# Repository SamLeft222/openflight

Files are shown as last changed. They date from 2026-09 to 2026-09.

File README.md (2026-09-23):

<p align="center">

  DIY Golf Launch Monitor using the OPS243-A Doppler Radar.
</p>

<p align="center">
  <a href="https://discord.gg/w8hhG4WVMN">
    
  </a>
  <a href="https://buymeacoffee.com/colemangolfs">
    
  </a>
</p>

<p align="center">
  Related projects:
  <a href="https://github.com/open-flight/openflight-enclosure">Enclosure</a>
  &middot;
  <a href="https://github.com/open-flight/openflight-mobile">Mobile App</a>
</p>

> [!WARNING]
> **This project is in active development.** Features may be incomplete, unstable, or change without notice. Contributions and bug reports are welcome!

## Overview

OpenFlight is an open-source golf launch monitor built around the OPS243-A
Doppler radar, with an optional TI IWR6843 angle radar.

### What It Measures

- **Ball Speed**: 15-200 mph range with ±0.5% accuracy (OPS243-A)
- **Club Speed**: Detected from pre-impact readings (OPS243-A)
- **Smash Factor**: Ball speed / club speed ratio
- **Launch Angle**: Measured by the IWR6843; estimated when no trusted radar angle is available
- **Club Path**: Experimental pre-impact estimate from the IWR6843
- **Spin Rate**: Experimental candidate from rolling-buffer I/Q; not used for carry by default
- **Carry Distance**: Ballistic model with explicit fallbacks for missing measurements

### Hardware at a Glance

| Component | What it does | ~Cost |
|---|---|---|
| OPS243-A Radar | Ball speed, club speed, experimental spin | $249 |
| Raspberry Pi 5 | Runs everything | $130 |
| 7" Touchscreen | Shows shot data | $46 |
| SparkFun SEN-14262 | Impact sound trigger for shot capture | $18 |
| Power supply + accessories | | $27 |
| **Subtotal, no angle radar** | | **~$400** |
| TI IWR6843LEVM + cable | Launch angle, experimental club path | $156 |
| **Total with angle radar** | | **~$556** |
| K-LD7 (×2) + FTDI adapters | Launch angle + club path (**deprecated**) | $140 |

Without an angle radar you still get ball speed, club speed, smash factor,
experimental spin, and estimated carry. The angle radar adds measured launch
angle and experimental club path.

> **⚠️ The K-LD7 angle radars are deprecated.** The supported angle radar is now the **TI IWR6843**. Don't buy K-LD7s for a new build; their software support remains for existing builds only. See the [full parts list](docs/get-started/parts.md) for details and links.

> **The IWR6843 needs custom firmware** — the stock TI demo doesn't expose the raw radar cube OpenFlight needs. A validated prebuilt image ships in `firmware/releases/`, so flashing it doesn't require the TI toolchain. See the [IWR6843 Operator Guide](docs/iwr6843/index.md).

## Getting Started

### 1. Get the parts

See the **[Parts List](docs/get-started/parts.md)** for everything you need with purchase links.

### 2. Wire it up

Follow the **[Sound Trigger Wiring Guide](docs/build/sound-trigger.md)** to connect the SEN-14262 to the OPS243-A. The (deprecated) K-LD7 modules connect via USB — no wiring needed.

**Adding the IWR6843 angle radar?** The Pi cannot power both radars over USB, so
the OPS243 moves to the Pi's GPIO UART header while the TI board takes the USB
port. Do it in this order, validating each step before the next — doing both at
once makes any failure ambiguous:

1. **[Move the OPS243 from USB to the Pi GPIO UART](docs/build/ops243-uart.md)** — rewire and confirm the OPS still triggers on its own.
2. **[IWR6843 Operator Guide](docs/iwr6843/index.md)** — wire, flash the firmware, mount, aim, and measure geometry.

If your OPS243-A has **WiFi**, you cannot use the GPIO UART — its WiFi module
already drives the radar's UART receive line. Use a separately powered USB hub
instead; see the operator guide's Option B.

### 3. Set up the Pi

Flash Raspberry Pi OS (64-bit), plug in the radars, then run the interactive setup:

```bash
git clone https://github.com/jewbetcha/openflight.git
cd openflight
./scripts/setup/setup.sh
```

The script installs everything and walks you through the one-time hardware
configuration (radar flash setup, legacy K-LD7 device naming, auto-start, and
optional cloud sync) with prompts. It's safe to re-run any time.
See the **[Raspberry Pi Setup Guide](docs/setup/raspberry-pi.md)** for details and troubleshooting. Touchscreen installations can use the **[Startup Splash Screen](docs/setup/splash-screen.md)** guide to install a terminal-free desktop launcher with immediate startup progress.

### 4. Hit balls

```bash
# Default: rolling buffer mode with sound trigger
scripts/start-kiosk.sh

# With the IWR6843 angle radar (OPS243 on the Pi GPIO UART).
# Geometry values are examples — measure your own; see the operator guide.
scripts/start-kiosk.sh --iwr6843 \
  --ops-port /dev/ttyAMA0 \
  --iwr6843-tee-m 1.372 --iwr6843-net-m 4.064 \
  --iwr6843-tilt-deg 5.5 --iwr6843-radar-height-m 0.229 \
  --iwr6843-ball-height-m 0.021

# With legacy K-LD7 hardware (measure the mount tilt first)
scripts/start-kiosk.sh --kld7 --kld7-mount-tilt <measured-degrees>

# Swing speed training (air swings / speed sticks, no sound trigger)
scripts/start-kiosk.sh --swing-speed

# Development mode (no hardware)
scripts/start-kiosk.sh --mock

# With Geekworm X1202/X1206 battery monitoring
scripts/start-kiosk.sh --battery geekworm
```

The IWR6843 example values are not universal. Measure the geometry from the
antenna center and follow the [operator guide](docs/iwr6843/mounting.md#measure-the-geometry);
wrong values bias the result instead of producing an obvious startup error.

Then open http://localhost:8080 or use the touchscreen. Footer tabs switch
between Live, Stats, Shots, Camera, Players, and Debug. Tap the footer logo for
units, theme, and language; the footer power icon opens shutdown confirmation.
On Live, tap a metric to pin it top-left while keeping all metrics visible. Use
the Replay action on camera-backed shots to open a touch-friendly slow-motion
impact clip. The MP4 is generated only when Replay is selected and is cached
beside the raw camera capture. For a TV or tablet, use
[TV Display Mode](#tv-display-mode).

### 5. Sync to the cloud (optional)

OpenFlight can push your sessions to the **FlightWeb** cloud so you can review
shots from any device. It's opt-in, and **raw radar data never leaves your
Pi** — only shot results and session metadata are uploaded (verify with
`openflight-cloud push --dry-run`).

`setup.sh` offers to enable this and link your Pi. To do it by hand:

```bash
openflight-cloud link       # pair this Pi (enter a short code in your browser)
openflight-cloud status     # linked? queued? parked?
```

Once linked, sessions sync automatically (on session end and via a ~10-minute
timer that heals wifi outages). See the **[Cloud Sync Guide](docs/using/cloud-sync.md)**
for details.

### TV Display Mode

OpenFlight also serves a fullscreen-friendly browser display for tablets, TV browsers, or a Chrome tab cast to Chromecast.

1. Start OpenFlight as usual with `scripts/start-kiosk.sh`.
2. Find the OpenFlight host on your LAN — its hostname (see below) or its IP address.
3. Open `http://<openflight-host>:8080/display` from another laptop, tablet, or TV browser.
4. For Chromecast, open the display page in Chrome and use Chrome's built-in **Cast** feature to cast the tab.

> **Prefer the hostname over the IP.** Raspberry Pi OS broadcasts its hostname over
> mDNS (Avahi), so `http://openflight.local:8080/display` keeps working even when the
> Pi's DHCP lease expires and it comes back on a different address — a bookmarked IP
> breaks unless you reserved it on your router. Set the name in Raspberry Pi Imager's
> **Hostname** field when you flash the card; the default is `raspberrypi`, i.e.
> `raspberrypi.local`. The viewing device has to support mDNS — macOS, iOS, Windows 10+
> and most Linux desktops do, but some smart-TV browsers don't, so use the IP there.

This is browser/tab casting only. OpenFlight does not include native Cast SDK support yet.

### Swing Speed Training

For air swings and speed-stick training, OpenFlight can use the OPS243-A fast
speed stream directly instead of waiting for impact audio. Start it with
`scripts/start-kiosk.sh --swing-speed`; the server emits `swing_speed` events
with peak club speed, rep duration, reading count, and session stats. See the
**[Swing Speed Training Guide](docs/using/swing-speed.md)** for setup and
tuning options.

## How It Works

### System Architecture

```
SEN-14262 ── trigger ──► OPS243-A ── I/Q ──► RollingBufferMonitor
                                                   │
IWR6843 (optional) ── angle + club path ───────────┤
                                                   ▼
                                           Flask + WebSocket ──► React UI
```

1. **Sound trigger fires** — SEN-14262 detects club impact, triggers OPS243-A HOST_INT
2. **OPS243-A dumps buffer** — I/Q data is analyzed for ball speed, club speed, and an experimental spin candidate
3. **IWR6843 correlates** — The optional angle radar uses the same impact edge for launch angle and experimental club path
4. **Carry computed** — The ballistic model uses trusted measurements and fills missing inputs with documented fallbacks
5. **UI updates** — Shot data emitted via WebSocket to the React frontend

### Doppler Radar Basics

The OPS243-A transmits a 24 GHz signal. When it bounces off a moving object (the golf ball), the frequency shifts proportionally to the object's speed — this is the Doppler effect. At 24.125 GHz, each 1 mph of speed creates a ~71.7 Hz Doppler shift.

### Positioning

Place the OPS243-A **3-5 feet behind the tee**, pointing down the target line:

```
                Ball Flight Direction
                ======================>

[Tee]  ←--- 3-5 ft ---→  [OPS243-A]
```

The IWR6843 has stricter mounting and measurement requirements; use the
[operator guide](docs/iwr6843/mounting.md#mount-and-aim-the-radar) rather than assuming it
shares the OPS243 position.

## Configuration

### Radar Settings for Golf

| Setting | Value | Why |
| --- | --- | --- |
| Mode | Rolling buffer | Raw I/Q capture for precise speeds and experimental spin |
| Sample Rate | 30 ksps | Supports up to ~208 mph ball speed |
| Capture | 4096 I/Q samples | ~136 ms around impact |
| Trigger | Sound (SEN-14262) | ~10 µs hardware latency via HOST_INT |
| Min Ball Speed | 15 mph | Minimum valid ball speed threshold (35 mph for speed-triggered mode) |
| DC Mask | ~15 mph exclusion zone | Reject body movement and environmental noise |

These are applied automatically — the one-time flash configuration is handled
by the setup script.

### Python API

```python
from openflight.rolling_buffer import RollingBufferMonitor

monitor = RollingBufferMonitor()   # auto-detects the OPS243-A
monitor.connect()
monitor.start()

print("Swing when ready...")
shot = monitor.wait_for_shot(timeout=60)
if shot:
    print(f"Ball Speed: {shot.ball_speed_mph:.1f} mph")
    print(f"Est. Carry: {shot.estimated_carry_yards:.0f} yards")

monitor.stop()
monitor.disconnect()
```

## Limitations

- **Cosine error**: If ball doesn't travel directly toward/away from radar, measured speed will be slightly lower than actual
- **Spin detection**: The live multitaper value is experimental and is not used for carry by default. Short indoor flight windows and multipath make individual readings unreliable; see [Rolling Buffer and Spin Detection](docs/how-it-works/rolling-buffer.md).
- **K-LD7 speed aliasing** (deprecated hardware): The K-LD7 max speed is 62 mph, so it's used only for angle/distance, not speed

## Hardware Diagnostic

To verify the OPS243, sound trigger, and legacy K-LD7 path:

```bash
uv run python scripts/hardware-test/diagnose.py
```

The diagnostic checks the OPS243 transport, rolling-buffer persistence,
software and hardware triggers, and any connected K-LD7 radars. IWR6843 builds
use the [operator guide's first-capture checks](docs/iwr6843/verify.md#verify-the-first-capture).

Missing optional hardware (like the horizontal K-LD7) is reported as a skip rather than a failure. Pass `--require-all` to fail on skips, or `--no-interactive` to skip the sound-trigger prompt in unattended runs.

## Project Structure

```
openflight/
├── src/openflight/
│   ├── ops243.py              # OPS243-A radar driver
│   ├── launch_monitor.py      # Shot detection & club/ball separation
│   ├── server.py              # Flask server and shot orchestration
│   ├── session_logger.py      # JSONL session logging
│   ├── rolling_buffer/        # OPS capture and signal processing
│   ├── iwr6843/               # Current angle radar
│   ├── kld7/                  # Legacy angle radar
│   ├── sim/                   # Simulator connector framework
│   └── cloud/                 # FlightWeb uploader
├── ui/                        # React frontend
├── scripts/                   # Utility & setup scripts
├── docs/                      # Documentation
└── pyproject.toml
```

## Community

Join the **[OpenFlight Discord](https://discord.gg/w8hhG4WVMN)** to ask build
questions, share results, and follow development.

## Contributing

Contributions welcome! See [CONTRIBUTING.md](CONTRIBUTING.md) for guidelines.

Areas of interest:

- **Better spin detection**: A dechirped Doppler-sideband estimator is in development (`scripts/analysis/replay_spin_dechirp.py`) — help validating it against launch-monitor truth data is especially welcome
- **Mobile app**: Bluetooth connection to phone

### Running Tests

```bash
uv run pytest tests/ -v
```

## Documentation

📖 **Full documentation site: <https://openflight.dev/docs/>**

Build it locally with `make docs` (serves at `localhost:8000`).

- **[Parts List](docs/get-started/parts.md)** — What to buy
- **[Sound Trigger Wiring](docs/build/sound-trigger.md)** — How to wire the sound trigger
- **[Raspberry Pi Setup](docs/setup/raspberry-pi.md)** — Full setup guide
- **[Electron Kiosk Shell](docs/electron-kiosk-shell.md)** — Why the kiosk runs in Electron and how self-updating could work later
- **[Battery Monitoring](docs/using/battery.md)** — Provider architecture, UI states, and shared Pi support
- **[Geekworm X1202/X1206 Operator Guide](docs/build/battery.md)** — Batteries, Pi setup, native telemetry, and warnings
- **[IWR6843 Operator Guide](docs/iwr6843/index.md)** — Wire, flash, mount, aim, and calibrate the angle radar
- **[LIS3DH Inclinometer Setup](docs/build/inclinometer.md)**: Add enclosure-level compensation to IWR6843 tilt
- **[OPS243 USB → GPIO UART Migration](docs/build/ops243-uart.md)** — Required before adding the IWR6843
- **[IWR6843 Firmware Developer Guide](docs/development/firmware.md)** — Build the firmware from source (not needed to flash the prebuilt image)
- **[Enclosure & Case](docs/build/enclosure.md)** — The printed IARC v3 case
- **[Hardware Diagnostic](docs/setup/raspberry-pi.md)** — Pi setup, auto-start, and troubleshooting
- **[Simulator Connectors](docs/using/simulator/index.md)** — Stream shots to GSPro, OpenGolfSim, PAR-TEE, and others
- **[Cloud Sync](docs/using/cloud-sync.md)** — Push filtered sessions to FlightWeb
- **[Rolling Buffer & Spin Detection](docs/how-it-works/rolling-buffer.md)** — Production capture and experimental spin details
- **[Dechirped-Sideband Spin Replay](docs/development/spin-replay.md)** — Next-gen spin estimator test bench
- **[Camera and YOLO Experiments](docs/development/camera-yolo.md)** — Optional, non-production vision work
- **[Legacy K-LD7 Setup](docs/legacy/index.md)** — Existing K-LD7 builds only
- **[K-LD7 Ball Detection Theory](docs/legacy/ball-detection-theory.md)** — How angle detection works (deprecated hardware)
- **[Observability & Log Shipping](docs/using/observability.md)** — Ship logs to Grafana Cloud
- **[Contributing Guide](CONTRIBUTING.md)** — How to contribute
- **[Changelog](docs/changelog.md)** — Version history

## License

GNU Affero General Public License v3.0 or later (AGPL-3.0-or-later) - see LICENSE file.

## Acknowledgments

- [OmniPreSense](https://omnipresense.com/) for the OPS243-A radar and documentation
- The golf hacker community for inspiration

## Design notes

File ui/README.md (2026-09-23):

# OpenFlight UI

The OpenFlight dashboard: a React + TypeScript + Vite app that connects to the
backend over `socket.io`. The kiosk is a tabbed instrument panel (Live, Stats,
Shots, Camera, Profiles, Debug) plus a screen-mounted display mode at `/display`.

This README covers frontend development. For the hardware, the radar pipeline,
and how the whole system fits together, see the [root README](../README.md).

## Quick start

You need Node 22.12 or newer (`electron@44` will not install cleanly on Node 20).

### Frontend-only (recommended for UI work)

Runs Vite plus a Node Socket.IO mock on port `8080` — no Python, hardware, or
`uv` required:

```bash
npm install
npm run dev:mock
```

Open `http://localhost:5173`. Use **Simulate** to generate shots. The mock
speaks the same Socket.IO events as the real backend (`shot`, `session_state`,
club/profile changes, clear/delete, stub cloud upload and shutdown).

### Against the real / Python mock backend

Start a backend without hardware from the repo root:

```bash
scripts/start-kiosk.sh --mock
```

Then in `ui/`:

```bash
npm install
npm run dev
```

See the [root README](../README.md#getting-started) for full-stack options.

The Vite server runs on port `5173`. When served there, the UI assumes the
backend is at `http://localhost:8080`. Point it elsewhere with
`VITE_SOCKET_URL`:

```bash
VITE_SOCKET_URL="http://localhost:8081" npm run dev
```

`/api/*` requests from the Vite origin are proxied to `http://localhost:8080`
(so shutdown works under `npm run dev` / `dev:mock`).

## Scripts

| Script | Description |
| --- | --- |
| `npm run dev` | Dev server with hot reload (needs a backend) |
| `npm run dev:mock` | Vite + Node mock backend on port 8080 |
| `npm run mock-server`  | Node mock Socket.IO server alone |
| `npm run build` | Type-check and build the production bundle |
| `npm run preview` | Serve the production build locally |
| `npm run lint` | ESLint |
| `npm run test` | Vitest unit tests |
| `npm run format` | Format `src/` with Prettier |
| `npm run format:check` | Check formatting without writing |

## How the UI connects

The app is entirely client-side. Everything flows through one socket connection.

- **`utils/serverOrigin.ts`** resolves the backend origin: `VITE_SOCKET_URL` if
  set, otherwise `http://localhost:8080` when running on the Vite dev port
  (`5173`), otherwise the page's own origin (the production case, where the
  backend serves the built UI).
- **`services/socketService.ts`** owns the connection. It receives events like
  `shot`, `session_state`, `camera_capture_settings`, and `trigger_status`, and
  sends commands like `set_club`, `clear_session`, `simulate_shot`, and
  `set_camera_capture_settings`. Read it before assuming what the
  backend emits. **`mock-server/`** implements that contract in Node for
  `npm run dev:mock`.
- **State** lives in `stores/` (Zustand: shots, system, camera, debug, profiles, …).
- **Shutdown** posts to `/api/shutdown` to stop the connected backend (stubbed
  as a no-op by the Node mock).

### Profiles socket contract

Shots are attributed to a server-owned **profile** — a person or a place — with
a stable id. There is no browser-local roster: the server is the only source of
truth, sent as one snapshot plus five mutations.

Server → client:

- `profiles` — `{ profiles: Profile[], active_profile_id: string }`. Sent on
  connect and after every mutation below. `Profile` is
  `{ id, name, created_at, settings }`.
- `session_cleared` — `{ profile_id: string, shots: Shot[] }`, sent after
  `clear_session`.

Client → server:

- `get_profiles` — request a fresh `profiles` snapshot.
- `set_active_profile` — `{ profile_id }`. Switches which profile new shots
  attribute to.
- `add_profile` — `{ name }`. Creates a profile and makes it active.
- `rename_profile` — `{ profile_id, name }`. Renames in place; the id (and
  every shot already attributed to it) is unchanged.
- `remove_profile` — `{ profile_id }`. The server refuses to remove the active
  profile, the last remaining profile, or a profile that still has session
  shots. Clear that profile's session first.
- `clear_session` — `{ profile_id }` (defaults to the active profile).
  Deletes that profile's shots; other profiles are untouched.

Shots carry `profile_id` and `profile_name` (a snapshot at capture time) for
logging / external consumers. The kiosk UI renders the current profile name
from the `profiles` roster (joined by `profile_id`), so renaming updates the
on-screen name for past shots.

**Kiosk shell.** Footer tabs switch views. The footer logo opens a sheet for
units (MPH/YDS vs KMH/M), dark/light theme, language, and simulator status.
The footer power icon is always visible and opens a
shutdown confirmation. Change club (or training implement) lives on the Live
header. Tap a Live metric to pin it top-left while keeping all metrics visible.
Camera-backed shots add a **Replay** action in the Live header and a play button
in Shots. Selecting either action asks the backend to lazily create and cache a
60 FPS MP4; no video conversion runs automatically after a shot. The full-screen
player includes touch controls, a scrubber, an impact marker, and retryable
preparation/playback errors.

The pin is stored in
`localStorage` under `openflight.hero-metric`. Theme is stored under
`openflight.theme` (default dark). Those keys live in the **current browser
profile**. Electron does not share Chromium's profile; see
[Electron Kiosk Shell](../docs/electron-kiosk-shell.md#browser-local-state-breaking-on-first-electron-launch).

**Display mode** lives at `/display`: a compact, fullscreen-friendly dashboard
for mounted screens and TVs. The [root README](../README.md#tv-display-mode)
covers casting it.

**Launch Daddy** is a hidden overlay. Five taps on the header connection LED
and title toggle it. When on, new shots can fire an animation; tap the brand
mark to turn it off.

Touch and type conventions for the Pi kiosk are in [`AGENTS.md`](./AGENTS.md).

## Languages

UI copy lives in `src/i18n/`. English, Spanish, French, and Portuguese ship
today. Pick a language from the footer menu (**Language** dropdown). The choice
is stored in `localStorage` under `openflight.locale:v1`.

### Add a language

1. Copy `src/i18n/en.ts` to `src/i18n/<code>.ts` (use a short BCP 47 language
   code such as `de` or `ja`).
2. Translate every value. Keep the same keys; TypeScript will fail the build if
   a key is missing.
3. Register it in `src/i18n/index.ts`:
   - Add the id to `LocaleId`.
   - Add `{ id, nativeName, htmlLang }` to `LOCALES` (`nativeName` is the
     language’s own name, shown in the dropdown).
   - Import the catalog and add it to `catalogs`.
4. Run `npm test` — a catalog that drifts from English keys fails.

Do not translate profile names, club tile codes (`7i`, `DR`), or unit
abbreviations (`MPH` / `YDS`).

## Project layout

A few files do most of the work. This is illustrative, not exhaustive —
components carry co-located `.css` and `.test.tsx` files.

```text
src/
  App.tsx                    # tabs, display routing, session wiring
  main.tsx                   # entry point (applies stored theme)
  i18n/                      # EN/ES/FR/PT catalogs
  theme/                     # dark/light tokens
  services/socketService.ts  # socket connection, events, backend commands
  hooks/useSocket.ts         # connects on mount
  utils/serverOrigin.ts      # backend origin resolution
  stores/                    # Zustand (shots, system, camera, profiles, …)
  components/
    panel/                   # Live, Stats, Shots, Camera, Profiles, chrome
    ui/                      # MetricCard, TabBar, Button, SegmentedControl
    DisplayMode.tsx          # /display
    DebugPanel.tsx
    LaunchDaddy/             # hidden overlay
mock-server/                 # Node Socket.IO mock for frontend-only development
```

## Troubleshooting

**Socket won't connect.** Confirm a backend is running on port `8080` (or set
`VITE_SOCKET_URL`). For UI-only work, use `npm run dev:mock`. Connection logs
come from `services/socketService.ts`.

**Build fails.** `npm run build` surfaces TypeScript and bundling errors; `npm
run lint` catches the rest.

---

Contributing guidelines (setup, code quality, PRs) live in
[CONTRIBUTING.md](../CONTRIBUTING.md).

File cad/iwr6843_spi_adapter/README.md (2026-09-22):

# IWR6843LEVM → Raspberry Pi 5 SPI adapter

Small 2-layer board (34.0 × 25.9 mm) that plugs into the IWR6843LEVM's 60-pin
**J1** (MMWAVEICBOOST) connector and brings the radar's SPI-A port out to a
0.1" header for jumper wires to the Pi 5. The goal is to move the ~733 KB
wide-profile dump over SPI (~0.6 s at 10 MHz) instead of the ~1 Mbaud CP2105
UART (~7 s).

> **Status: rev A, not yet built or tested.** ERC, DRC and schematic–PCB
> parity pass. The firmware SPI path and Pi driver do not exist yet.

## What's on the board

| Ref | Part | Job |
|---|---|---|
| J1 | Samtec **QTH-030-01-L-D-A** (bottom side) | Mates the LEVM's J1 (QSH-030-01-L-D-A), 5.00 mm stack |
| J2 | 1×11 2.54 mm header (top side) | Jumpers to the Pi 5 |
| U1, U2 | SN74LVC2G34DBVR, powered by **radar 3V3** | Pi → radar: SCLK, MOSI, CS (U2 ch1 spare, input grounded) |
| U3 | SN74LVC2G34DBVR, powered by **Pi 3V3** | Radar → Pi: MISO, HOST_INTR |
| R1 | 100k to radar 3V3 | CS inactive (high) while the Pi pin is floating |
| R2–R5 | 100k to GND | No floating buffer inputs (SCLK, MOSI, MISO, INTR) |
| R6, R7 | 33 Ω | Damp ringing on the INTR/MISO jumpers |
| C1–C3 | 100 nF | Buffer decoupling (C3 is on the bottom) |

**Why buffers:** the IWR6843's digital I/O is not failsafe (TI SWRU585: do not
drive the pins without VIO present). The LVC2G34 has Ioff partial-power-down
(≤10 µA leakage at VCC = 0), so whichever side loses power, its buffer goes
inert and nothing back-feeds the unpowered chip.

## Before ordering (can't be checked in software)

1. **Mating orientation.** The footprint assumes QTH pin *n* mates LEVM J1
   (QSH) pin *n*, with the −A alignment pins on the row-01 side (per the
   Samtec land pattern). Print `fab/gerbers/*B_Cu*` at 1:1, or check a
   Samtec mated-pair drawing, and confirm pin 1 against the LEVM's J1
   silkscreen.
2. **Clearance behind the LEVM.** The adapter sits 5 mm under the LEVM's
   bottom side. The only bottom-side parts are J1, C3 (0.9 mm) and **J2's
   pin tails, which must be trimmed flush (≤1 mm)** so they can't touch the
   LEVM's bottom components (J6 is nearby).

## Ordering and assembly (PCBWay turnkey)

Run `./export_fab.sh` (regenerates, runs ERC/DRC, and exports into `fab/`):

| Upload | File |
|---|---|
| Gerbers + drills | `fab/iwr6843_spi_adapter-gerbers.zip` |
| BOM (PCBWay columns, MPNs) | `fab/pcbway_bom.csv` |
| Centroid / CPL | `fab/pcbway_cpl.csv` (origin = board lower-left, J2 excluded) |
| Assembly drawings | `fab/assembly/assembly_top.pdf`, `fab/assembly/assembly_bottom_mirrored.pdf` |

PCB options: 2 layers, FR-4, 1.6 mm, 1 oz, **ENIG** (flat pads for the
0.5 mm-pitch J1; HASL is too uneven), min track/spacing 5/5 mil, min hole
0.3 mm, tented vias, any mask colour.

Assembly: turnkey, **both sides** (J1 and C3 on the bottom, the rest on top).
J2 is not in the BOM or CPL. Solder it yourself and trim the tails flush.
Notes to include with the order:

> J1 (Samtec QTH-030-01-L-D-A) is on the BOTTOM side; its -A alignment pins go
> into the two 1.02 mm NPTH holes; pin 1 is marked on the bottom assembly
> drawing. U1-U3 pin 1 per the silkscreen dot. J2 (1x11 header) is NOT
> assembled. Please send placement confirmation images before production.

## LEVM setup

* Set switch **S1.4 OFF**. This routes SPI-A through the on-board TS3A5018
  mux to J1 instead of the CAN transceivers (PROC116A sheet 13). OpenFlight
  does not use CAN. TI's "functional mode" table leaves S1.4 ON; that is
  the only change.
* Keep powering the LEVM over USB as today. Do not connect J1 pin 2 (5V).

## Pi 5 wiring (jumpers ≤15 cm, cable-tie each signal to its GND)

| Adapter J2 | Signal | Pi 5 pin |
|---|---|---|
| 1 | 3V3 (powers U3) | 1 |
| 2, 4, 6, 8, 10 | GND | 6, 9, 14, 20, 25 |
| 3 | HOST_INTR (data ready) | 22 (GPIO25) |
| 5 | MISO | 21 (GPIO9) |
| 7 | MOSI | 19 (GPIO10) |
| 9 | SCLK | 23 (GPIO11) |
| 11 | CS | 24 (GPIO8 / CE0) |

None of these clash with the OPS243 UART wiring (Pi pins 2/4, 6, 8, 10, 11).
Enable SPI with `dtparam=spi=on`. Start at ≤10 MHz on jumpers.

## First power-up checks

1. Adapter only, unplugged from the LEVM: continuity between J2 even pins and
   J1 GND. No short between Pi 3V3, radar 3V3 and GND.
2. Plugged in, **everything off**: beep from J1-side nets to the LEVM's 0 Ω
   links: CS → R7, SCLK → R9, MOSI → R11, MISO → R12, INTR → R10
   (PROC116A sheet 8). This confirms the mating orientation.
3. Power the LEVM only: radar 3V3 is present at C1/C2 and U3 stays unpowered.
   Then the Pi only, then both.

## Sources

| Fact | Source |
|---|---|
| J1 pins 19/21/23/25 = SPI CS/CLK/MOSI/MISO, 16 = HOST_INTR, 4/6 = 3V3, even 20–50 = GND | TI PROC116A schematic, sheets 5, 8, 13 |
| VIOIN = 3.3 V, SPI-A behind TS3A5018, S1.4 selects SPI/CAN | PROC116A sheets 5 and 13; SWRU585 table 5-1 |
| J1 = QSH-030-01-L-D-A | PROC116A BOM |
| QTH land pattern, 5.00 mm mated height | Samtec QTH footprint Rev D, QTH print table 1 |
| LVC2G34 pinout, Ioff, DBV0006A land pattern | TI SN74LVC2G34 datasheet |

## Regenerating

Everything is generated from `generate.py` (schematic, footprints, project)
and `build_pcb.py` (placement, routing, pours). `NETS`/`PARTS` are the single
source of truth for both. Edit those, never the KiCad files.

```bash
K=/Applications/KiCad/KiCad.app/Contents
$K/Frameworks/Python.framework/Versions/Current/bin/python3 generate.py
$K/MacOS/kicad-cli sch erc --severity-all iwr6843_spi_adapter.kicad_sch
$K/MacOS/kicad-cli pcb drc --schematic-parity --refill-zones --severity-all iwr6843_spi_adapter.kicad_pcb
```

Expect only `lib_symbol_issues` / `lib_footprint_issues` warnings if your
KiCad has no global library tables configured. They are environment notices,
not design errors.

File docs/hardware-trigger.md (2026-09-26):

# OPS243 Internal Hardware Trigger

OpenFlight’s `hardware` trigger mode lets the OPS243-A decide when a rolling-buffer capture starts. It is opt-in; the kiosk default remains the existing SEN-14262 sound trigger.

## OPS243 firmware prerequisite

Hardware-trigger mode requires **OPS243-A firmware v1.3.2 or newer in the 1.3
release train**. Firmware v1.3.1 has a vendor data-sequence bug and is rejected.
The driver queries `?V` before sending the internal trigger setup commands and
fails fast if the reported version is from an older or different release train,
malformed, or unavailable. Update the physical OPS243 using the manufacturer’s
firmware procedure before running `--trigger hardware`; this application does
not flash the radar.

## Methodology

The host configures the radar once and then waits for the radar’s completed rolling-buffer dump. The host does not poll speed reports or send `S!` for each shot:

1. Put the radar in idle mode with `PI`.
2. Set a temporary outbound `ST-90` guard before entering rolling-buffer mode.
   `GC` can restore the detector units to m/s before `US` is sent; 90 is below
   the 30 ksps ceiling of 93.2 m/s and is still above ordinary startup motion
   if the board retained mph units.
3. Enter rolling-buffer mode with `GC`, then resend the guard because `GC`
   resets detector settings.
4. Restore the detector settings that `GC` resets: 30 ksps and MPH units first,
   then raise the temporary guard to `ST-200` while the remaining settings are
   written: 128 samples, `X=2`, outbound filtering, JSON plus magnitude output,
   and the configured `S#n` split.
5. Restore the magnitude gate `SMn`, then restore the requested `ST-n` last and allow the 4,096-sample history to fill.
6. Wait for the board-triggered dump, parse the I/Q payload, and reject it if it has no outbound ball-speed reading at or above 35 mph.
7. Re-arm with the same temporary guard around `GC`, restore the cached settings, and wait for the buffer to fill again. A serial write timeout keeps the capture and reports a retryable re-arm failure instead of discarding the shot.

The implementation is intentionally limited to the OPS243 trigger path; the
experimental analysis and UI work remain outside this focused change.

## Defaults and command

| Setting | Hardware-mode default |
|---|---:|
| Trigger threshold | 25 mph |
| Trigger magnitude | 25 (`SM25`) |
| Pre-trigger split | 6 segments (`S#6`) |
| Sample rate | 30 ksps (required) |
| Minimum accepted outbound ball speed | 35 mph |

Run the mode directly with:

```bash
openflight-server \
  --trigger hardware \
  --trigger-threshold 25 \
  --trigger-magnitude 25 \
  --pre-trigger-segments 6 \
  --sample-rate 30
```

The kiosk script forwards the same settings:

```bash
scripts/start-kiosk.sh --trigger hardware
```

Use `--trigger-threshold`, `--trigger-magnitude`, and `--pre-trigger-segments` to override the hardware path. `S#6` applies only to this new mode. The established sound path continues to use `--sound-pre-trigger` and keeps its existing default and behavior:

```bash
scripts/start-kiosk.sh --trigger sound --sound-pre-trigger 16
```

The internal trigger does not depend on the SEN-14262 sound edge. Existing sound-trigger wiring can remain installed, but selecting `hardware` is the software choice that activates the OPS243 internal trigger.

## Raspberry Pi retest checklist

Before treating a PR as ready for merge, run the hardware path on the target Pi and record the observations in the PR body:

Also run the unchanged sound path with the same representative shots:

```bash
scripts/start-kiosk.sh --trigger sound
```

I was unable to regression test the sound trigger.

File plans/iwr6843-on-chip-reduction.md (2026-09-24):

# Plan: IWR6843 On-Chip Data Reduction

> Source: offline study on 2026-09-24 of 70 shots paired with a Garmin R10
> (sessions `20260923_130739`, `131647`, `134628`; dense IQ8 profile).

## Problem

The IWR6843 result arrives ~6.4 s after impact. 5.3 s of that is streaming
the full 537 KB capture over the 1 Mbaud UART; Pi processing is ~1.1 s. The
launch-angle pipeline only ever reads a small part of that capture.

## Approach

The chip sends a small **power overview** first; the Pi runs its **unchanged**
ball tracker and OPS-guided track search on it, then requests only the thin
**strips** of complex data along the chosen track (or each candidate track).
Every tracking and estimation decision stays on the Pi, so estimator changes
never require reflashing.

Measured with the Phase 0 reference model on all 77 saved captures
(`scripts/iwr6843/evaluate_reduced_transfer.py`):

| Shot type | Captures | Bytes (median) | Transfer | Today |
|---|---|---|---|---|
| Baseline track (1 strip request) | 46 | 105 KB | ~1.0 s | 537 KB, 5.3 s |
| OPS-guided search (2 strip requests) | 31 | 280 KB | ~2.7 s | 537 KB, 5.3 s |
| All | 77 | | **~1.0 s median** | 5.3 s |

Transfer times assume today's measured ~103 KB/s. The Pi must still wait for
the OPS ball speed (~1.9 s) before confirming a track, so the expected
end-to-end IWR result is ~2.5-3 s instead of ~6.4 s. These are estimates from
byte counts, not hardware measurements.

## Evidence (offline, 70 paired shots)

1. **The angle fit is local to the track.** Given the same track and the full
   capture's noise power, a +/-1-bin strip (38.5 KB IQ8) reproduced the LCMF
   angle bit-for-bit on 62/62 shots (burst MTI scope). Horizontal was
   identical on every shot that had one.
2. **The tracker and OPS-guided search read only `loop_power(mti)`** inside the
   ball gates (2.25 m to net - 0.25 m; bins 48-98 on the current profiles).
   Bins outside the gates cannot change a detection.
3. **Overview precision.** A log-encoded uint16 power map (1/256-octave steps)
   left accuracy vs the R10 unchanged (solid shots, R10 LA > 5, n = 50: typical
   2.16 deg, mean 3.81 deg, 24 within 2 deg, same as full data); median shift
   from the full-data angle 0.00 deg, one shot moved 10.7 deg. uint8 at 0.5 dB
   or 1 dB was worse (mean 4.08 / 4.53 deg, more >5 deg misses): rejected.
4. **Both MTI scopes are needed.** Running the OPS-guided search on the burst
   map only raised the mean error from 3.81 to 4.48 deg and moved one shot
   37.5 deg. The window-scope map is sent every time (27.6 KB).
5. **Tracker sensitivity.** `find_ball` is a seeded RANSAC; changing a single
   detection reshuffles its draws. Bit-identical output is therefore not a
   usable acceptance test for any change to the overview; accuracy vs a
   reference is.

## Architectural decisions

- **Decision logic stays on the Pi.** The chip computes MTI, power, and noise
  and serves strips. It never chooses a track or an angle.
- **`l3dump` is kept unchanged** as the fallback path and for `--debug` raw
  captures.
- **Overview contents** (vertical TX pair 0/2, the same data the Pi uses today):
  - burst-scope and window-scope `loop_power`, rows = frame x loop, columns =
    gate bins only, log-encoded int16 (`round(log2(p) * 256)`, with
    -32768 reserved for exactly zero);
  - burst- and window-scope noise power as float32, computed exactly as
    `PreparedShotDump.noise_power` (median of `|mti|^2` over all valid bins);
  - window-scope per-bin static means (complex64, vertical pair, every bin
    any frame window holds), so the Pi can form window-scope MTI from strips
    (~6 KB);
  - the existing per-frame descriptors (start, count, time delta) and header.
- **Strips reuse the existing v7 variable-width timed format**, IQ8 as stored,
  all 3 TX (the horizontal proxy uses the third TX). One contiguous window per
  frame; the union of candidate corridors when several tracks are requested.
  The format needs at least one bin per frame, so an unrequested frame carries
  the first bin of its window.
- **The ring stays frozen** from `l3overview` until `l3release`, or until a
  firmware timeout (proposal: 10 s) re-arms it if the Pi disappears.
- **Gate bins are configured by the Pi** (`overviewCfg <loBin> <hiBin>`,
  derived from the net distance) so firmware and tracker cannot drift.
- **Lossless vertical projection.** Today `project_tx_pair` re-quantises IQ8
  with a new per-frame scale derived from the frame's maximum. With strips
  that maximum changes, so the projection must keep the stored IQ8 values
  exactly. Offline, the lossless projection moved individual angles (median
  0.43 deg in the full pipeline) without changing accuracy vs the R10
  (typical 1.94 vs 1.79 deg, n = 43), so this is a behaviour change to accept
  deliberately, not a fix.
- **Feature flag.** The reduced transfer ships behind
  `--iwr6843-reduced-transfer` with automatic fallback to `l3dump` on any
  protocol error, timeout, or malformed response.

## Out of scope / open questions

- **Club path** (experimental) uses pre-impact frames outside the ball gates.
  Either drop it in reduced mode or request an additional club strip.
- **On-chip compute time** for MTI + power + two medians on the R4F is not
  measured; the estimate is tens of ms. The DSP stays unused.
- **UART round-trip latency** for request/response is not measured.
- **Build toolchain.** Resolved: the Docker toolchain builds the release
  byte-for-byte (Phase 1).

---

## Phase 0: Python chip model and host refactor (no firmware)

**User stories**: As a developer, I can prove on saved dumps that the reduced
transfer produces the same shots before any firmware is written.

### What to build

A reference "chip model" that turns a full dump into an overview and serves
strip requests, and a host path that consumes overview + strips through the
existing tracker, OPS-guided search, and LCMF. `find_ball` and
`_candidate_tracks_for_scope` accept a precomputed power map;
`PreparedShotDump` accepts supplied noise values and window-scope means.

### Acceptance criteria

- [x] The chip model's overview and strips are packed/parsed by one
      executable definition (`openflight.iwr6843.reduced`), with round-trip
      and malformed-input tests.
- [x] With an unquantised overview, the reduced path matches the full-data
      path: 77/77 saved captures, including the 31 that ran the OPS-guided
      search -- bit-for-bit with the original float overview; with the rc2
      integer maths, identical statuses and launch angles within 3.4e-12 deg.
- [x] With the int16 log overview, accuracy vs the R10 pairs is unchanged:
      solid shots (n = 50) typical 2.16 deg, mean 3.81 deg, 24 within 2 deg,
      9 beyond 5 deg for both paths. No status changed; angle shift median
      0.00001 deg, p90 0.0001 deg; one capture moved 10.7 deg (a top the R10
      read at 2.0 deg, wrong on both paths).
- [x] Byte counts per shot are reported by
      `scripts/iwr6843/evaluate_reduced_transfer.py` (table above).
- [x] `project_tx_pair` preserves IQ8 values exactly; the change is covered by
      tests and its effect on the paired sessions is recorded. Replaying the
      70 paired shots (tilt 11.5): all 70 still accepted; angles moved median
      0.43 deg, p90 5.0 deg, max 12.3 deg. Solid shots vs R10 (n = 50):
      typical 2.03 -> 2.16 deg, mean 4.00 -> 3.81 deg, within 2 deg 25 -> 24,
      beyond 5 deg 8 -> 9 -- no net accuracy change.

---

## Phase 1: Reproducible firmware build

### What to build

Build the current release from source with the Docker toolchain once the TI
installers are available.

### Acceptance criteria

- [x] `make -C firmware docker-build` produces an image matching the
      checked-in `l3_dump_configurable_capture_20260818.bin`. Verified
      2026-09-24 on Apple Silicon (Docker Desktop 29.8, default Rosetta
      setting): the rebuild is byte-identical (SHA-256 `823ddd18...`), so no
      static-capture comparison is needed. Build with
      `RELEASE_NAME=<scratch>.bin` to avoid overwriting the release.

---

## Phase 2: Firmware overview, strips, and release

### What was built

* `firmware/iwr6843/reduced_overview.c/.h`: portable C89 core (no TI headers,
  no libm) that writes the overview and strips through a byte sink. Noise
  medians are exact (radix selection on the bits of non-negative doubles);
  log-power codes use a generated threshold table
  (`gen_reduced_log_table.py`). ~98 KB of working memory in MSS data RAM
  (151 KB of 192 KB used).
* `l3_dump.c` commands, registered after the build's last CLI entry:

  | Command | Effect |
  |---|---|
  | `overviewCfg <lo> <hi>` | Absolute range bins [lo, hi) the power maps cover |
  | `l3overview` | Freeze like `l3dump`, stream header + overview, **hold** the ring |
  | `l3strip <hex>` | 4 hex digits (start, count) per frame, `0000` for none; streams a timed dump of those bins from the held ring |
  | `l3release` | Resume capture; harmless when nothing is held |
  | `l3dump` (held) | Streams the held ring unchanged, then resumes |

  Requests are validated before any byte is streamed. `sensorStart` and
  `sensorStop` drop a hold. A priority-1 watch task resumes a hold the Pi has
  been silent on for 10 s. Every response from one freeze carries the
  temperature report read at the freeze.
* `IWR6843Radar.configure_overview_gate / read_overview / read_strips /
  release` on the Pi; `scripts/hardware-test/test_iwr6843_reduced_transfer.py`
  for the on-radar check.
* Candidate image: `firmware/candidates/l3_dump_reduced_transfer_rc3.bin`
  (not the release until this phase passes on hardware).

### Hardware results

**rc1 (2026-09-24, float maths):** all 23 checks passed on the radar --
overview and strips byte-identical to the reference from the same freeze
(3 cycles), release, error paths, and the 10 s timeout. But the overview
took 2.96 s in firmware (~2.3 s compute + ~0.6 s UART): ~200 cycles per
sample read, ~10x the estimate. That would leave the IWR result at ~4.5 s.

**rc2 (integer maths):** stored codes decoded once per pass into fast
memory; burst MTI power is exactly s^2 |L c - sum c|^2 / L^2 and window power
|n s c - T|^2 / n^2, each rounded once (reduced.py uses the same maths, so C
and Python still match byte-for-byte on all 80 captures). Against the float
full-capture path: 0 status changes, launch angles within 3.4e-12 deg
unquantised; accuracy vs the R10 unchanged. `stats` now also reports
`prepare_ms` (compute only). On the radar the Pi received only the command
echo: rc2 computes before its first byte, and the reader's 4 s stall timer
counted from the echo. Either the compute exceeded 4 s or it hung -- the
suspect is 64-bit integer multiplies and int64-to-double conversions, which
the R4F runs as library calls.

**rc3:** no 64-bit integers in the maths -- every intermediate is an exact
integer below 2^53, so it is carried in doubles with bit-identical results
(C and Python still match on all 80 captures). Compiling rc2's core with
the TI toolchain confirmed the suspicion: it called `__aeabi_lmul` and
`__aeabi_l2d` per value. rc3 calls neither, and the median's key is split
into 32-bit halves so its per-value work needs no 64-bit shift helper
either (those remain once per pass). The reader now starts its stall timer
only once the response has begun, and reports a missing response instead
of returning the echo.

On the radar (2026-09-24) rc3 passed all 23 checks: overview and strips
byte-identical to the reference from the same freeze in 3 cycles, release,
error paths, 10 s timeout, l3dump after the timeout. Timings (median):

| | rc1 | rc3 |
|---|---|---|
| compute before the first byte (`prepare_ms`) | ~2.3 s | 1.26 s |
| overview in firmware (`overview_ms`) | 2.96 s | 2.16 s |
| overview as the Pi receives it | 3.01 s | 2.22 s |
| strips (diagonal / whole windows / none) | 0.29 / 0.54 / 0.10 s | same |
| full `l3dump` | 5.28 s | 5.28 s |

The overview now lands ~0.3 s after the OPS speed (~1.9 s). Estimated IWR
result ~3.5-3.8 s vs ~6.4 s today (to be measured in Phase 3). The compute
is ~9 passes over the frozen ring at ~0.15 s each (sums, 3 per noise
median, 2 for the power maps); sharing the two medians' passes would remove
3 of them.

### Acceptance criteria

- [x] From one freeze, `l3overview` + `l3strip` output equals the Phase 0 chip
      model applied to an `l3dump` of the same freeze (rc1 and rc3 on the
      radar, 3 cycles each; host: all 80 saved captures).
- [ ] `stats` reports overview compute time, strip requests, release, and
      timeout re-arms (done); no HWA misses or EDMA errors across repeated
      cycles (not yet checked -- the hardware script does not read those
      counters).
- [x] A host that never sends `l3release` does not leave the radar frozen
      (timeout resumes capture after 10 s; checked on rc1 and rc3).
- [x] `l3dump` behaviour is unchanged (refactored into shared header, frame
      plan, and resume helpers; verified on the radar before, between, and
      after reduced transfers).

## Phase 3: Host integration behind a flag

### What was built

* `--iwr6843-reduced-transfer`: on a trigger edge the capture monitor sends
  `overviewCfg` (at start) and `l3overview`, and the radar holds its ring.
  `IWR6843Runtime.process_shot` measures the held capture with
  `measure_reduced`, fetching strips through `IWR6843CaptureMonitor.read_strips`
  (one serial lock), then `finish_capture` releases the ring.
* `--iwr6843-reduced-full-dump`: stream each held ring whole after measuring
  (offline analysis, club path) at the full dump's time cost. Without it the
  experimental club path is skipped (recorded in the transfer record).
* Fallbacks, each tested: overview failure -> ordinary `l3dump`; any failure
  of the reduced measurement -> the held ring streamed whole and measured as
  today; released firmware without `overviewCfg` -> full dumps (the runtime
  config reports the transfer actually in use); an unconsumed hold is
  released after 8 s (the firmware's own timeout is 10 s); shutdown releases
  a hold before `sensorStop`.
* `iwr6843_capture` session entries carry a `transfer` record: mode, overview
  bytes and seconds, strip bytes and seconds, fallback reason, full dump.

### Acceptance criteria

- [x] Per-stage timings (overview, strips, full dump) in the session log;
      processing is the shot's existing `pipeline_ms.iwr6843`.
- [x] Fallback to `l3dump` is exercised by tests for timeout, missing
      responses, strip failures, measurement errors, and old firmware.
- [ ] One R10-paired field session: IWR result latency and launch-angle error
      reported against the full-dump path.

---

## Phase 4: Default on

- [ ] Enabled by default after Phase 3 field validation; the flag remains to
      force `l3dump`.

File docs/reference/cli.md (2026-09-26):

---
icon: lucide/terminal
---

# CLI Flags

Every flag accepted by the server, grouped by subsystem.

`scripts/start-kiosk.sh` accepts most of these and forwards them. Use
`--dry-run` to print the exact command the script would run:

```bash
scripts/start-kiosk.sh --iwr6843 --dry-run
```

!!! note "Generated from the source"

    This table is derived from the argparse definitions in
    `src/openflight/server.py`. If a flag here disagrees with the code, the
    code is right — please open an issue.

## Server & web

Binding, ports, and debug output.

| Flag | Type / default | Description |
| --- | --- | --- |
| `--mock`, `-m` | flag | Run in mock mode without radar |
| `--mock-swing-speed` | flag | Run swing speed training mode with simulated reps and no OPS radar |
| `--host` | default `0.0.0.0` | Host to bind to (default: 0.0.0.0) |
| `--web-port` | int; default `8080` | Web server port (default: 8080) |
| `--startup-status-file` | path | Write structured initialization progress for the optional kiosk splash |
| `--debug`, `-d` | flag | Enable verbose FFT/CFAR debug output |
| `--radar-log` | flag | Log raw radar data to console (Python logging) |
| `--show-raw` | flag | Show raw radar readings in console (signed values) |

## OPS243 radar & transport

Serial port, baud, and sample rate.

| Flag | Type / default | Description |
| --- | --- | --- |
| `--port`, `-p` | — | Serial port for radar |
| `--ops-baud` | int | — |
| `--sample-rate` | int; default `30` | Radar sample rate in ksps (default: 30). Lower = longer buffer but lower max speed. 25=174mph/164ms, 27=187mph/152ms |

## Trigger & capture

How a capture is initiated and framed.

| Flag | Type / default | Description |
| --- | --- | --- |
| `--trigger` | choices: `sound`, `speed`, `hardware`; default `sound` | Trigger strategy |
| `--trigger-threshold`, `--speed-trigger-threshold`, `--trigger-speed` | float | Internal or host speed-trigger threshold in mph; hardware default `25` |
| `--trigger-magnitude` | int; default `25` | OPS243 internal trigger magnitude (`SMn`) |
| `--pre-trigger-segments` | int; default `6` | Hardware-trigger pre-trigger segments (`S#n`) |
| `--sound-pre-trigger` | int; default `16` | Pre-trigger segments S#n, 0-32 (default: 16 = 50/50 split, each segment ~4.27ms at 30ksps) |

## IWR6843 angle radar

The supported angle radar.

| Flag | Type / default | Description |
| --- | --- | --- |
| `--iwr6843` | flag | Enable TI IWR6843 L3 capture and LCMF-v1 vertical launch angle |
| `--iwr6843-port` | — | TI serial port (auto-detect by default) |
| `--iwr6843-config` | default `config/iwr6843_l3dump_wide_24f3ms_53bin_iq16.cfg` | TI RF config matching the flashed L3 firmware |
| `--iwr6843-cal` | default `config/iwr6843_calibration_reference.json` | TI complex array/range calibration JSON |
| `--iwr6843-trigger-pin` | int; default `17` | BCM GPIO receiving the shared sound-trigger edge (default: 17) |
| `--iwr6843-tee-m` | float; default `1.575` | Antenna-center to tee slant range in metres (default: 1.575) |
| `--iwr6843-net-m` | float; default `4.6` | Antenna-center to net range in metres (default: 4.6) |
| `--iwr6843-tilt-deg` | float | Override mount tilt from the TI calibration JSON |
| `--iwr6843-radar-height-m` | float | Override antenna-center height from the TI calibration JSON |
| `--iwr6843-ball-height-m` | float; default `0.04` | Ball-center height above the floor/mat (default: 0.040) |
| `--iwr6843-tx-order` | choices: `auto`, `normal`, `reversed`; default `auto` | TI TDM chirp order; auto reads the chirp masks from the cfg |
| `--iwr6843-capture-timeout` | float; default `16.0` | Maximum seconds an OPS shot waits for its TI UART dump |
| `--iwr6843-output-dir` | — | Raw TI dump directory when --debug is enabled (default: <session-log-dir>/iwr6843) |
| `--iwr6843-azimuth-offset-deg` | float | Azimuth of the radar boresight relative to the target line, in degrees. Positive means boresight points right of the target line. Added to the measured club path; 0 reports club path relative to boresight. |
| `--iwr6843-horizontal-phase-reference-rad` | float | Static target-line phase measured by horizontal aim calibration. Subtracted from the TX2 horizontal proxy before angle conversion. |

## Inclinometer

LIS3DH enclosure tilt compensation.

| Flag | Type / default | Description |
| --- | --- | --- |
| `--inclinometer` | flag | Enable LIS3DH enclosure pitch compensation for IWR6843 tilt |
| `--inclinometer-zero-offset` | float | Degrees added to raw LIS3DH pitch (default: 0) |

## Ballistics & spin

Carry model and spin handling.

| Flag | Type / default | Description |
| --- | --- | --- |
| `--ballistics` | flag | Use the physics-based carry simulator (drag + Magnus, RK4). This is the default; shots without a vertical launch angle fall back to the legacy table estimator. |
| `--no-ballistics` | flag | Disable the physics simulator and use the legacy carry table for all shots. |
| `--calculated-spin` | flag | Replace radar-measured spin with the kinematic estimate (170*v*sin(LA)^1.2) when the launch angle was measured. The 24 GHz OPS return carries no usable spin line (see src/openflight/spin_estimate.py); the measured value is kept in spin_rpm_measured for offline scoring |

## Swing speed

Club-only training mode.

| Flag | Type / default | Description |
| --- | --- | --- |
| `--swing-speed` | flag | Run club-only swing speed training mode (no impact or ball required) |
| `--swing-speed-threshold` | float; default `30.0` | Outbound speed threshold that starts a swing speed rep (default: 30 mph) |
| `--swing-speed-max` | float; default `130.0` | Maximum plausible swing speed accepted from OPS reports; use 0 to disable (default: 130 mph) |
| `--swing-speed-min-readings` | int; default `3` | Minimum qualifying radar readings required to count a swing speed rep (default: 3) |
| `--swing-speed-single-peak` | float; default `60.0` | Peak speed that can count as a swing from one radar reading (default: 60 mph) |
| `--swing-speed-num-reports` | int; default `8` | Number of OPS speed candidates to report per sample cycle (default: 8) |
| `--swing-speed-end-ms` | float; default `1000.0` | Milliseconds below threshold before ending a swing speed rep (default: 1000) |
| `--swing-speed-cooldown-ms` | float; default `750.0` | Cooldown after a swing speed rep before accepting another (default: 750) |
| `--swing-speed-rejected-cooldown-ms` | float; default `100.0` | Cooldown after an ignored short motion before re-arming (default: 100) |

## Logging & session data

Where session logs go and what they capture.

| Flag | Type / default | Description |
| --- | --- | --- |
| `--session-location`, `-l` | default `range` | Location identifier for session logs (e.g., 'range', 'course', 'home') |
| `--log-dir` | — | Directory for session logs (default: ~/openflight_sessions) |
| `--profiles-path` | path | Profile store (default: `OPENFLIGHT_PROFILES_PATH` or `~/.config/openflight/profiles.json`) |
| `--no-logging` | flag | Disable session logging |

## Simulators & power

Outbound connectors and battery status.

| Flag | Type / default | Description |
| --- | --- | --- |
| `--battery` | — | Show battery and external-power status using the selected provider |
| `--sim` | flag | Enable simulator connectors from config/sim.json (GSPro / OpenGolfSim / PAR-TEE). Off by default. |

## High-speed camera capture

Optional rolling-buffer capture and replay. See [camera setup](../camera/README.md).

| Flag | Type / default | Description |
| --- | --- | --- |
| `--camera-capture` | flag | Enable high-speed rolling-buffer capture and replay |
| `--camera-capture-width` | int; default `640` | Capture width |
| `--camera-capture-height` | int; default `400` | Capture height |
| `--camera-capture-fps` | float; default `300` | Capture frame rate |
| `--camera-capture-pre-ms` | float; default `150` | Milliseconds retained before the trigger |
| `--camera-capture-post-ms` | float; default `50` | Milliseconds retained after the trigger |
| `--camera-capture-exposure-us` | int; default `1000` | Exposure seed for startup calibration |
| `--camera-capture-gain` | float; default `4.0` | Analogue-gain seed for startup calibration |
| `--camera-capture-mount-height-m` | float; default `0.20955` | Camera optical-center height above the hitting surface |
| `--camera-capture-horizontal-offset-deg` | float; default `0` | Target-line correction added to horizontal launch angles |
| `--camera-capture-lateral-offset-m` | float; default `0` | Camera position relative to radar center; positive is target-right |
| `--camera-capture-roll-deg` | float; default `0` | Clockwise image-roll correction for preview and geometry |
| `--camera-capture-stream` | `raw` or `main-y`; default `raw` | Camera stream to persist |
| `--camera-capture-scaler-crop` | `X,Y,W,H` | Optional Picamera2 scaler crop |
| `--camera-capture-rotate-180` | flag | Rotate saved frames 180 degrees |
| `--camera-capture-mirror-horizontal` | flag | Mirror saved frames left-to-right after rotation |

## K-LD7 (deprecated)

Retained for existing builds only. See [Legacy (K-LD7)](../legacy/index.md).

| Flag | Type / default | Description |
| --- | --- | --- |
| `--kld7` | flag | [DEPRECATED] Enable K-LD7 vertical angle radar (launch angle) |
| `--kld7-port` | — | K-LD7 vertical serial port (auto-detect if not specified) |
| `--kld7-angle-offset` | float; default `1.5` | K-LD7 vertical boresight offset in degrees. Not user-measurable without a corner reflector; 1.5 is the calibrated default for the standard mount (default: 1.5) |
| `--kld7-mount-tilt` | float | K-LD7 vertical radar mount tilt in degrees. REQUIRED with --kld7 — measure it with a phone inclinometer against the radar face; there is no default because a wrong tilt silently corrupts the launch angle |
| `--kld7-ball-distance` | float; default `5.0` | Radar-to-tee distance in feet (default: 5.0) |
| `--net-distance` | float; default `10.0` | Ball-to-net/screen distance in feet (two_ray). For nets beyond the ~11ft FSK range wrap, far-flight frames are de-aliased and kept instead of dropped (default: 10.0; nets at/inside the wrap are unaffected). |
| `--kld7-radar-height-inches` | float; default `4.0` | K-LD7 radar height above the ball in inches, used by the ball-speed cosine correction geometry (default: 4.0) |
| `--kld7-vertical-raw` | flag | TEST MODE: show the raw vertical launch angle for every shot the estimator produces, bypassing all display guardrails (plausibility, soft-lane, estimator-agreement, confidence floor). Default off. |
| `--kld7-horizontal` | flag | [DEPRECATED] Enable K-LD7 horizontal angle radar (club path) |
| `--kld7-horizontal-port` | — | K-LD7 horizontal serial port |
| `--kld7-horizontal-offset` | float | K-LD7 horizontal angle offset in degrees (default: 0.0) |

## Wrapper-only flags

Handled by `scripts/start-kiosk.sh` itself rather than passed through.

| Flag | Description |
| --- | --- |
| `--dry-run` | Print the command that would run, then exit |
| `--startup-splash` | Show component progress while the kiosk starts |
| `--startup-splash-port` | Port used by the temporary splash server |
| `--port`, `--web-port` | Set the kiosk web port |
| `--radar-port`, `--ops-port` | Forward the OPS serial port as the server's `--port` |
| `--buffer-split` | Buffer split preset (`balanced`, `post-heavy`, `pre-heavy`) or raw segment count |

## Related

- [Running & modes](../using/running.md) — the common invocations
- [Configuration files](configuration.md) — settings that are not flags
- [Constants](constants.md) — values compiled in rather than passed

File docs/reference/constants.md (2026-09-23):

---
icon: lucide/sliders
---

# Constants

Values compiled into the code rather than passed as flags. Change them by
editing the module, not the command line.

## Capture and FFT

`src/openflight/rolling_buffer/processor.py`

| Constant | Value | Meaning |
| --- | --- | --- |
| `SAMPLE_RATE` | 30,000 | Samples per second |
| `WINDOW_SIZE` | 128 | Samples per FFT window |
| `FFT_SIZE` | 4,096 | Zero-padded FFT size |
| `STEP_SIZE_STANDARD` | 128 | Non-overlapping step |
| `STEP_SIZE_OVERLAP` | 32 | Overlapping step, high resolution |
| `DC_MASK_BINS` | 150 | ~15 mph exclusion zone around DC |
| `MAGNITUDE_THRESHOLD` | 3 | Minimum peak magnitude |
| `MIN_PEAK_SEPARATION_BINS` | 50 | ~5 mph; rejects sidelobe duplicates |
| `MAX_PEAKS_PER_DIRECTION` | 3 | |

`--sample-rate` overrides the rate at runtime. Lowering it lengthens the buffer
but reduces the maximum measurable speed: 25 ksps gives 174 mph over 164 ms,
27 ksps gives 187 mph over 152 ms.

## Radar physics

| Constant | Value | Meaning |
| --- | --- | --- |
| `WAVELENGTH_M` | 0.01243 | 24.125 GHz |
| `MPS_TO_MPH` | 2.23694 | |
| `ADC_RANGE` | 4,096 | 12-bit ADC |
| `VOLTAGE_REF` | 3.3 | Reference voltage |

At 24.125 GHz, 1 mph produces roughly a 71.7 Hz Doppler shift.

## Club extraction

| Constant | Value |
| --- | --- |
| `CLUB_BRANCH_HISTORY_MS` | 30.0 |
| `CLUB_BALL_ONSET_SEARCH_MS` | 10.0 |
| `CLUB_BALL_MATCH_MIN_MPH` | 4.0 |
| `CLUB_BALL_MATCH_FRACTION` | 0.06 |
| `CLUB_PLATEAU_LOOKBACK_MS` | 18.0 |
| `CLUB_PLATEAU_GUARD_MS` | 4.0 |
| `CLUB_PLATEAU_QUANTILE` | 0.70 |
| `CLUB_BALL_CONTAMINATION_RATIO` | 0.95 |
| `CLUB_TERMINAL_START_MS` | −2.5 |
| `CLUB_TERMINAL_END_MS` | 1.0 |
| `CLUB_MAX_PLAUSIBLE_SPEED_MPH` | 150.0 |

## Spin detection

Amplitude-envelope demodulation. See
[rolling buffer & spin detection](../how-it-works/rolling-buffer.md).

| Constant | Value | Meaning |
| --- | --- | --- |
| `SPIN_BANDPASS_BW_HZ` | 700 | ±700 Hz around ball Doppler |
| `SPIN_BANDPASS_ORDER` | 4 | Butterworth order |
| `SPIN_ENVELOPE_FFT_SIZE` | 8,192 | Zero-padded envelope FFT |
| `SPIN_MIN_SEAM_HZ` | 33.0 | ~2,000 RPM floor |
| `SPIN_MAX_SEAM_HZ` | 200.0 | 12,000 RPM ceiling |
| `SPIN_MIN_SAMPLES` | 600 | ~20 ms minimum ball signal |
| `SPIN_SNR_HIGH` | 8.0 | High-confidence threshold |
| `SPIN_SNR_MEDIUM` | 5.0 | Medium-confidence threshold |
| `SPIN_SNR_MIN` | 2.5 | Minimum to report at all |
| `SPIN_AUTOCORR_MIN` | 0.3 | Minimum normalised correlation |
| `SPIN_MIN_CYCLES` | 2 | Minimum seam cycles |
| `SPIN_DC_LEAKAGE_BINS` | 1 | Low bins zeroed |
| `SPIN_LOW_BAND_SUSPECT_MAX_RPM` | 3,100.0 | |
| `SPIN_DETREND_POLY_ORDER` | 3 | |
| `SPIN_SIGNAL_LOSS_SMOOTH_SAMPLES` | 90 | ~3 ms moving average |

`SPIN_CONFIDENCE_HIGH` (0.7, in `launch_monitor.py`) is the threshold above
which measured spin is trusted for physics.

## Ballistics

`src/openflight/ballistics.py` — see
[ballistics & carry](../how-it-works/ballistics.md) for the model and its
references.

| Constant | Value |
| --- | --- |
| `BALL_MASS_KG` | 0.04593 |
| `BALL_RADIUS_M` | 0.02135 |
| `AIR_DENSITY_STD` | 1.225 |
| `CD_POLY` | (0.1304, 0.9287, -0.8259) |
| `CL_POLY` | (0.0504, 1.2031, -1.1490) |
| `SP_FIT_MAX` | 0.75 |
| `SPIN_DECAY_RATE` | 0.04 |
| `GRAVITY` | 9.81 |
| `DT_SECONDS` | 0.002 |
| `MAX_FLIGHT_SECONDS` | 15.0 |
| `SAMPLE_INTERVAL_S` | 0.05 |

## Thresholds

| Value | Setting |
| --- | --- |
| Minimum ball speed | 15 mph (35 mph in speed-triggered mode) |
| Trigger latency, `sound` | ~10 µs |
| Trigger latency, `speed` | ~5–6 ms |
| Rolling-buffer dump | 40,556 bytes |
| K-LD7 OS-CFAR threshold factor | 8.0 *(deprecated hardware)* |

## Related

- [CLI flags](cli.md) — what can be changed at runtime
- [Configuration files](configuration.md) — settings held in files

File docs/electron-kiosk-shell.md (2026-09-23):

# Electron Kiosk Shell

`scripts/start-kiosk.sh` launches the React UI inside Electron
(`ui/electron/main.js`) rather than shelling out to whatever browser
happens to be installed on the Pi. This document explains why that's an
improvement, and sketches how it could support self-updating later. It does
not describe anything implemented yet beyond the shell itself — see
[Auto-Updates (Future Work)](#auto-updates-future-work).

## Why Electron Instead Of A System Browser

The old `launch_kiosk_browser` tried `chromium-browser`, then `chromium`,
then `google-chrome`, then `firefox` — whichever the OS image happened to
have, with `--kiosk` flags tuned mostly for Chromium. That worked, but it
carried a few risks an Electron shell removes:

| Concern | System browser | Electron shell |
|---|---|---|
| Rendering engine version | Whatever `apt` installed/upgraded on that Pi — can silently drift between units or after an OS update | Pinned in `ui/package-lock.json` (`electron@44.1.0` today), identical across every Pi until deliberately bumped |
| Kiosk lockdown | `--kiosk` behaves differently across Chromium, Chrome, and Firefox; Firefox's kiosk mode in particular is looser (menu/shortcuts still reachable) | One `BrowserWindow` with `kiosk: true`, no application menu, and `setWindowOpenHandler` denying any popup — the same guarantees everywhere |
| Startup noise | Chromium's "restore previous session" / crash bubbles needed extra flags (`--disable-session-crashed-bubble`) to suppress | Electron has no Chromium session-restore prompt to suppress. Its **default session still persists** under the app `userData` directory (`~/.config/openflight-ui` on Linux) — [Session](https://www.electronjs.org/docs/latest/api/session), [app.getPath('userData')](https://www.electronjs.org/docs/latest/api/app#appgetpathname). That is a *different* profile from system Chromium (`~/.config/chromium` / `chromium-browser`) |
| Maintenance surface | A 4-branch `if/elif` detection ladder to keep working across Raspberry Pi OS Bookworm/Bullseye, Lite/Desktop images | One binary, one launch path; `npm ci` makes the exact runtime reproducible in CI the same way any other dependency is |
| Extensibility | A browser tab is sandboxed from the OS — no filesystem, process, or native API access | The Electron **main process** is a regular Node.js process with full OS access, which is what makes [self-updating](#auto-updates-future-work) possible at all |

The old detection ladder is kept as a fallback (`launch_kiosk_browser` still
tries `chromium-browser`/`chromium` if `ui/node_modules/.bin/electron` is
missing), so a Pi that hasn't installed Electron doesn't lose its kiosk
entirely — it just loses the guarantees above until Electron is installed.

`start-kiosk.sh` builds `ui/dist` only when that directory is missing. If the
UI is already built but Electron is not installed, it *tries* `npm install`
when Node.js is 22.12+. Old Node, an offline Pi, or a failed install logs a
warning and continues to the Chromium fallback instead of aborting startup.

## Browser-local state (breaking on first Electron launch)

Electron does **not** reuse the system Chromium profile. The first time a unit
switches from Chromium to Electron, browser-local `localStorage` looks empty:

| Data | Storage | Survives the switch? |
|---|---|---|
| Profiles and shot logs | Server (`~/.config/openflight/profiles.json`, session JSONL) | Yes |
| Units, theme, language, pinned Live metric | Chromium `localStorage` | No — re-set in the footer / Live grid |
| Validation annotations (comparator device, speed, notes) | `localStorage` key `openflight-validation-entries` | No |

**Before** switching a validation unit to Electron, export the Shots CSV
(**Export CSV** on the Shots tab) while still on Chromium. After the switch,
re-enter units, theme, language, and the pinned metric once.

This is an accepted one-time reset, not a silent migration. Chromium's LevelDB
profile is not copied into Electron `userData`.

## What Didn't Change

Electron here is a shell, not a rewrite: `ui/electron/main.js` opens a
`BrowserWindow` and points it at the same URL the browser used to load
(`http://localhost:8080`, served by Flask from `ui/dist`). The React app,
the WebSocket connection (`socketService.ts`), and the Flask server are
untouched — `getServerOrigin()` still resolves to `window.location.origin`,
which is the Electron window's origin now instead of a browser tab's.

## Process Ownership

`scripts/kiosk-browser.sh` launches Electron (or the Chromium fallback) with
`setsid`, so the whole browser tree, including the zygote, GPU, network and
renderer helpers Chromium forks, lives in one process group that nothing
else on the Pi belongs to. Shutdown signals that group and nothing else. The
earlier cleanup matched the Electron binary path with `pkill -f`, which also
killed kiosks started by *other* launcher instances; see the changelog for
the boot-service crash loop that exposed it. `start-kiosk.sh` additionally
holds `/tmp/openflight-kiosk-<port>.lock` for its lifetime and exits with
status 3 if another instance already holds it.

## Auto-Updates (Future Work)

Nothing below is implemented. It's worth writing down now because "Electron
shell" and "auto-update" are usually mentioned in the same breath, and
because OpenFlight's deployment shape (a small fleet of Pis you personally
maintain, not a public app store release) points toward a different design
than the default Electron answer.

There are two separate things that could be "updated," and they call for
different mechanisms.

### 1. UI content (the React build) — already effectively live

Electron loads a URL, not a bundled copy of `ui/dist`. Whatever Flask is
currently serving is what the window shows. So once a Pi has pulled a new
`ui/dist` (via the existing `git pull && npm run build` flow in
[splash-screen.md](setup/splash-screen.md#updating-an-existing-pi)) and the
service restarts, the Electron window shows the new UI on its next launch —
no Electron-specific update logic needed for this layer. This is already
true today.

### 2. The Electron shell itself

`electron` is a normal `devDependency` in `ui/package.json`. Bumping its
version is a normal dependency bump: change the version, `npm install`,
commit the updated lockfile, `git pull` on each Pi. No runtime auto-update
machinery is needed for this either, as long as updates continue to arrive
through `git pull` + reinstall rather than an out-of-band download.

Installing that package (not running the Electron binary) needs **Node.js
22.12+** on the Pi. Node 20 prints `npm WARN EBADENGINE` for `electron@44`
and its `@electron/get` helper. See the Node install step in
[Raspberry Pi setup](setup/raspberry-pi.md).

### 3. The interesting case: OpenFlight self-updating without an SSH session

The capability an Electron main process adds that a browser tab never had
is **the kiosk can update itself**, because `main.js` runs as a full
Node.js process on the Pi rather than inside a sandboxed tab. Two designs,
in increasing order of complexity:

**A. Main-process-driven `git pull` (recommended starting point)**

The main process periodically (or on a UI-triggered "Check for Updates"
action, via a `contextBridge` preload script) does the same thing an
operator does by hand today:

1. `git fetch` and compare `HEAD` against `origin/<branch>`.
2. If behind: `git pull`, `uv sync`, `npm run build` (in `ui/`).
3. Decide how to apply it:
   - Content-only change (`ui/` touched, `ui/electron/` and
     `ui/package.json`'s `electron` version untouched) → `win.loadURL()`
     again, or just wait for the operator's next launch.
   - Shell change (Electron itself bumped, or `main.js` changed) →
     `app.relaunch(); app.exit(0)`, or restart the systemd unit
     (`systemctl --user restart openflight` / `sudo systemctl restart
     openflight`, per `scripts/setup/openflight.service`) so the new
     `main.js` is picked up.

This reuses the exact update path already documented for manual updates —
it just runs it from inside the app instead of over SSH. It also keeps
using GitHub as the source of truth, so no new release infrastructure,
signing, or hosting is required.

Things to get right if this is built:
- **Trust boundary:** whatever triggers the pull (a timer or a UI button)
  must not be reachable by anything the Flask server exposes over the
  network — this must stay a main-process-only action, not a socket event
  or HTTP endpoint, so a device on the same LAN can't trigger arbitrary
  `git pull`/`uv sync` execution on the Pi.
- **Partial-failure safety:** a `git pull` that succeeds but an `npm run
  build` that fails should not leave the Pi worse off than before — keep
  the previous `ui/dist` until the new build succeeds (e.g. build to a
  temp directory and swap), and skip the restart on build failure.
- **Mid-round updates:** don't apply an update (especially the
  shell-restart kind) while a shot/session is in progress; gate it on
  session/idle state the same way the splash screen gates on startup state.
- **Network dependence:** the Pi may be on a golf-sim LAN with no general
  internet access even when it can reach GitHub, or vice versa — the check
  should fail closed (skip silently) rather than block startup.

**B. `electron-updater` + a packaged build**

The conventional Electron answer — `electron-builder` packages the app,
`electron-updater`'s `autoUpdater.checkForUpdatesAndNotify()` polls a feed
(GitHub Releases, S3, or a self-hosted static server) and swaps the
installed build. This is the right model for shipping to users you don't
operate the hardware for.

It's a bigger lift than option A here, for two reasons specific to this
project:
- It requires the packaging step this shell deliberately skipped (see the
  original Electron-shell decision: "just run from source, no installers").
  `ui/dist` would need to be bundled into the package rather than loaded
  live from Flask, which reintroduces the "which layer updates independently"
  question this doc just resolved for the source-checkout model.
- `electron-updater`'s Linux auto-update support is limited to the AppImage
  format. That's buildable for `arm64` (Raspberry Pi OS 64-bit, which this
  fleet already requires), but it's a new build target, a new artifact to
  test on real hardware, and a release/signing pipeline to stand up — none
  of which exists for this project today.

**Recommendation:** start with (A) if/when self-updating is prioritized. It
matches the fleet's actual shape (Pis you `git pull` on, not an app store
audience), reuses infrastructure that already exists (`uv sync`, `npm run
build`, the systemd unit), and doesn't require adopting a packaging and
release pipeline before there's a concrete need for one. Revisit (B) only if
OpenFlight starts distributing prebuilt images to people who don't run `git
pull` themselves.

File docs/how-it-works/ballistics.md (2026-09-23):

---
icon: lucide/trending-up
---

# Ballistics & Carry

Carry is not measured — it is simulated. OpenFlight integrates the ball's
trajectory from the launch conditions it measured, accounting for drag and the
Magnus force from spin.

Implemented in `src/openflight/ballistics.py`.

## The model

Three forces act on the ball: gravity, aerodynamic drag opposing motion, and
the Magnus lift generated by backspin.

$$
\vec{F} = m\vec{g}
- \tfrac{1}{2}\rho A C_d \lvert\vec{v}\rvert \vec{v}
+ \tfrac{1}{2}\rho A C_l \lvert\vec{v}\rvert^2 \hat{n}
$$

The coefficients depend on the **spin parameter** $S_p = r\omega / v$ — the
ratio of surface speed to translational speed:

$$
C_d = a + b\,S_p + c\,S_p^2
\qquad
C_l = \max\!\left(0,\; d + e\,S_p + f\,S_p^2\right)
$$

Both are second-order polynomials in $S_p$, the form **Ferguson, McNally &
McPhee (2022)** fitted to 1040 measured shots; the coefficients are their
published values. Lift rises with spin, peaks near $S_p \approx 0.52$ and then
falls, which is what the measured data shows and what a saturating form cannot
represent. Above $S_p = 0.75$, the top of the fitted range, both curves are held
at their end value rather than extrapolated.

These parametric forms are consistent with **Bearman & Harvey (1976)** and
**Kensrud & Smith (2018)** for dimpled balls past the drag crisis
(Re ≈ 5×10⁴–2×10⁵), which covers the full range of realistic golf shots.

Spin decays exponentially over the flight:

$$
\omega(t) = \omega_0 \, e^{-\lambda t}
$$

at roughly 4 %/s per **Kiratidis & Leinweber (2018)** — small per second, but it
matters across a six-second flight.

## Constants

| Constant | Value | Note |
| --- | --- | --- |
| `BALL_MASS_KG` | 0.04593 | USGA **maximum**-conforming ball, 45.93 g |
| `BALL_RADIUS_M` | 0.02135 | 42.7 mm diameter |
| `AIR_DENSITY_STD` | 1.225 kg/m³ | Sea level, 15 °C ISA |
| `CD_POLY` | (0.1304, 0.9287, -0.8259) | $C_d$ polynomial $(a, b, c)$ |
| `CL_POLY` | (0.0504, 1.2031, -1.1490) | $C_l$ polynomial $(d, e, f)$ |
| `SP_FIT_MAX` | 0.75 | Top of the fitted $S_p$ range; curves held beyond it |
| `SPIN_DECAY_RATE` | 0.04 /s | ≈4 %/s |
| `GRAVITY` | 9.81 m/s² | |
| `DT_SECONDS` | 0.002 | 500 Hz integration |
| `MAX_FLIGHT_SECONDS` | 15.0 | Safety cap |
| `SAMPLE_INTERVAL_S` | 0.05 | Cadence of returned trajectory points |

!!! note "Why the maximum-conforming ball"

    Mass and radius use the USGA maximum rather than an average, so carry
    estimates are upper-bounded by the rules rather than by a guess about which
    specific ball is in play.

## Integration

Fourth-order Runge-Kutta at 500 Hz. RK4 error is $O(\Delta t^5)$, so at this
step size the integration is effectively exact for the timescales involved;
noticeably larger steps begin to shorten long drives.

The solver returns points every 50 ms rather than every step — integration still
runs at the full rate, but the sampled list keeps WebSocket payloads and session
logs a reasonable size.

Real shots terminate in 5–9 seconds. The 15-second cap exists so a solver
instability or pathological input fails loudly instead of spinning.

## Inputs and fallbacks

The simulator needs ball speed, launch angle, and spin. Ball speed always comes
from the OPS243. The other two may be missing:

| Input | When present | When missing |
| --- | --- | --- |
| Launch angle | IWR6843 measurement | Falls back to the legacy carry table estimator |
| Spin | OPS243, if confidence is high | Club-typical spin from TrackMan PGA Tour averages, by `ClubType` |

Measured spin is only trusted above `SPIN_CONFIDENCE_HIGH` (0.7). Below that,
the club-typical value is used — see
[rolling buffer & spin detection](rolling-buffer.md) for why.

`--calculated-spin` forces the kinematic estimate
$170 \cdot v \cdot \sin(\text{LA})^{1.2}$ even when a measured value exists,
keeping the measured number in `spin_rpm_measured` for offline scoring.

Shot finalization in the server is the only place that writes
`carry_spin_adjusted` for a live shot: the simulator when it can run, the
spin table otherwise. The same committed number is what the kiosk shows and
what the simulator connectors receive.

## Disabling it

```bash
scripts/start-kiosk.sh --no-ballistics
```

Uses the legacy carry-table estimator for every shot. The simulator is the
default; shots without a vertical launch angle fall back to the table anyway.

## Related

- [Rolling buffer & spin detection](rolling-buffer.md) — where spin comes from
- [Constants](../reference/constants.md) — the full constant set

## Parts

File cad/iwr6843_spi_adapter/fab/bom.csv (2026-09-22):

Designator | Value | Footprint | MPN | Qty
C1-C3 | 100nF | Capacitor_SMD:C_0603_1608Metric | CL10B104KB8NNNC | 3
J1 | QTH-030-01-L-D-A | openflight_adapter:Samtec_QTH-030-01-L-D-A | QTH-030-01-L-D-A | 1
J2 | Pi5_jumpers | Connector_PinHeader_2.54mm:PinHeader_1x11_P2.54mm_Vertical |  | 1
R1-R5 | 100k | Resistor_SMD:R_0603_1608Metric | RC0603FR-07100KL | 5
R6,R7 | 33 | Resistor_SMD:R_0603_1608Metric | RC0603FR-0733RL | 2
U1-U3 | SN74LVC2G34DBVR | openflight_adapter:TI_DBV0006A | SN74LVC2G34DBVR | 3

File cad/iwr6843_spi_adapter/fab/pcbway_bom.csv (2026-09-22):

Line# | Qty | Designator | MPN | Manufacturer | Description | Package | Type
1 | 3 | C1,C2,C3 | CL10B104KB8NNNC | Samsung Electro-Mechanics | 100nF 50V X7R 0603 MLCC | C_0603_1608Metric | SMD
2 | 1 | J1 | QTH-030-01-L-D-A | Samtec | 0.5mm 2x30 Q Strip terminal, alignment pins, mates QSH-030-01 | Samtec_QTH-030-01-L-D-A | SMD
3 | 5 | R1,R2,R3,R4,R5 | RC0603FR-07100KL | YAGEO | 100k 1% 0603 resistor | R_0603_1608Metric | SMD
4 | 2 | R6,R7 | RC0603FR-0733RL | YAGEO | 33R 1% 0603 resistor | R_0603_1608Metric | SMD
5 | 3 | U1,U2,U3 | SN74LVC2G34DBVR | Texas Instruments | Dual buffer, Ioff partial-power-down, SOT-23-6 | TI_DBV0006A | SMD

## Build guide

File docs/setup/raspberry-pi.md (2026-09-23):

# Raspberry Pi Setup Guide

Complete guide for setting up OpenFlight on a Raspberry Pi 5 with the 7" touchscreen display.

## Prerequisites

Make sure you have all the hardware. See the **[Parts List](../get-started/parts.md)** for what to buy.

**Required:**
- Raspberry Pi 5 (4GB+ recommended)
- 7" Touchscreen Display
- MicroSD Card (32GB+)
- 27W USB-C Power Supply (official Pi 5 PSU recommended)
- OPS243-A Doppler Radar + USB cable
- SparkFun SEN-14262 sound detector (wired per the [Sound Trigger Wiring Guide](../build/sound-trigger.md))

**Optional:**
- TI IWR6843LEVM + data-capable micro-USB cable — measured launch angle and experimental club path; see the [IWR6843 Operator Guide](../iwr6843/index.md)
- Geekworm X1202 or X1206 UPS HAT — portable Pi 5 power using four separately purchased 18650 or 21700 cells; see the [battery monitoring overview](../using/battery.md) and [Geekworm operator guide](../build/battery.md)
- InnoMaker OV9281 global-shutter camera (~$30) — experimental vision work; see [Camera and YOLO Experiments](../development/camera-yolo.md)

**Optional (deprecated):**
- K-LD7 + FTDI adapter (×2) — for launch angle and club path (see [Parts List](../get-started/parts.md)). **Deprecated** — superseded by a more capable radar chip; don't buy for a new build. Supported for existing builds only.

## Setup

### 1. Install Raspberry Pi OS and Dependencies

Use Raspberry Pi Imager to flash **Raspberry Pi OS (64-bit)** to your SD card.

On the first boot, before cloning OpenFlight, you'll likely need a few dependencies to run the setup.sh script.

Run the following command:

```bash
sudo apt update && sudo apt install -y swig liblgpio-dev python3-dev
```

The UI/Electron kiosk shell needs **Node.js 22.12 or newer** to *install*
Electron. Raspberry Pi OS `apt` Node is often 18 or 20 and will print
`EBADENGINE` (or fail) for `electron@44`. A Pi that already has `ui/dist` can
still start: `start-kiosk.sh` falls back to system Chromium until Node is
upgraded and `npm install` in `ui/` succeeds. Install Node 22 LTS before a
first UI build or to actually run the Electron shell:

```bash
curl -fsSL https://deb.nodesource.com/setup_22.x | sudo -E bash -
sudo apt-get install -y nodejs
node -v   # should report v22.12.0 or later
```

If `./scripts/setup/setup.sh` updates `~/.bashrc`, you may need to run `source ~/.bashrc` (or open a new terminal) so your current shell picks up the new environment variables immediately without needing to reboot or re-login.

### 2. Run the setup script

Plug in the OPS243-A (and the K-LD7 adapters if you have them), then:

```bash
cd ~
git clone https://github.com/jewbetcha/openflight.git
cd openflight
./scripts/setup/setup.sh
```

The script installs everything, then walks you through the one-time hardware
configuration with prompts:

1. **Dependencies** — Python venv, packages, UI build, test run
2. **OPS243-A radar** — saves rolling buffer mode to the radar's flash
   (you'll be asked to unplug/replug the radar once)
3. **K-LD7 radars** (deprecated; if you have them) — identifies each radar by
   plugging them in one at a time, so OpenFlight always knows which is which
4. **Geekworm UPS** (optional) — enables native X1202/X1206 battery and
   external-power telemetry, Pi power settings, and desktop battery support
5. **Auto-start on boot** — optional systemd service
6. **Desktop shortcut** — optional
7. **FlightWeb cloud sync** — optional uploader and device linking

Every step can be skipped and the script is **safe to re-run** any time —
it picks up where you left off.

### 3. Start hitting balls

```bash
./scripts/start-kiosk.sh        # Default: rolling buffer + sound trigger
./scripts/start-kiosk.sh --mock # Mock mode (no hardware)
```

Then open `http://localhost:8080` or use the touchscreen.

For the current IWR6843 angle radar, use the measured startup command in the
[IWR6843 Operator Guide](../iwr6843/verify.md#start-openflight). Existing K-LD7
builds use `--kld7 --kld7-mount-tilt <measured-degrees>`; see
[Legacy K-LD7 Setup](../legacy/index.md).

### 4. (Optional) Stream to a golf simulator

To send shots to GSPro, OpenGolfSim, or another supported sim, copy the
example config and enable your simulator:

```bash
cp config/sim.example.json config/sim.json   # then edit host/port + "enabled": true
```

See **[Simulator Connectors](../using/simulator/index.md)** for the full guide.

---

## What the Script Configures (Reference)

You don't need this section unless something went wrong or you prefer to do
things by hand.

### IWR6843 Angle Radar

The setup script does not configure the IWR6843 — it needs custom firmware
flashed over the ROM bootloader, which requires physically moving a switch on
the board. That is covered end to end in the
**[IWR6843 Operator Guide](../iwr6843/index.md)**.

Do it in this order, and confirm each step works before starting the next:

1. **Move the OPS243 to the Pi GPIO UART** —
   [migration guide](../build/ops243-uart.md). The Pi cannot power both radars
   over USB, so the OPS243 has to vacate the USB port. Validate the OPS on its
   own after rewiring, before the TI board is involved at all.
2. **Flash the IWR6843** — operator guide, *Flash The IWR6843 Firmware*. A
   validated prebuilt image is in `firmware/releases/`, so the TI toolchain is
   not required. You only need the
   [firmware developer guide](../development/firmware.md) to build from source.
3. **Mount, aim, and measure geometry** — operator guide. The geometry values
   are passed on the command line and a wrong one silently biases the launch
   angle instead of erroring, so measure rather than estimate.

Re-flashing is only needed if the image in `firmware/releases/` changes. A
software update alone does not require it — compare the release filename against
what you flashed.

> [!WARNING]
> A **WiFi-equipped OPS243-A cannot use the GPIO UART.** Its WiFi module already
> drives the radar processor's UART receive line, so the Pi cannot send it
> commands, and OpenFlight must be able to reconfigure and rearm the OPS after
> every capture. Use a separately powered USB hub for both radars instead
> (operator guide, Option B).

### Geekworm X1202/X1206 UPS

The optional UPS setup is automated and safe to rerun:

```bash
sudo ./scripts/battery/geekworm/setup.sh
sudo reboot
./scripts/battery/geekworm/setup.sh --verify
```

It enables I2C, native Linux battery and charger devices, the Pi 5 EEPROM power
settings required by Geekworm, and the Raspberry Pi taskbar compatibility
package. It does not install automatic shutdown or charging-control services.

Cell type, board-revision power limits, physical installation, every system
change, and troubleshooting are documented in the
**[Geekworm X1202/X1206 Operator Guide](../build/battery.md)**.

### K-LD7 Device Names (Deprecated Hardware)

Existing K-LD7 builds need stable `/dev/kld7_vertical` and
`/dev/kld7_horizontal` names because USB adapter numbers can swap after a
reboot. Run the device wizard, then follow the legacy guide:

```bash
./scripts/setup/setup_kld7_devices.sh
./scripts/setup/setup_kld7_devices.sh --show
```

The wizard also installs the required FTDI low-latency rule. See
[Legacy K-LD7 Setup](../legacy/index.md) for mounting and startup, and
[K-LD7 Troubleshooting](../legacy/troubleshooting.md) for serial failures.

### Desktop Launcher And Startup Splash

OpenFlight can display component progress immediately after a desktop launch
without opening a terminal window. Install or refresh the user-local wrapper
and desktop entry with:

```bash
cd ~/openflight
scripts/setup/install_desktop_launcher.sh
```

The installer uses checkout-specific launcher and desktop filenames, preserving
multiple OpenFlight installations on the same Pi. Machine-specific device paths
and calibration remain outside Git. See the
[Startup Splash Screen](splash-screen.md) guide for configuration, screenshots,
error recovery, updating existing launchers, and rollback.

### Auto-Start on Boot

The setup script installs and enables a systemd service configured for your
username and install path.

<details>
<summary>Manual steps and service management</summary>

```bash
# Install (adjust User= and paths in the file if your username isn't the default)
sudo cp ~/openflight/scripts/setup/openflight.service /etc/systemd/system/
sudo systemctl daemon-reload
sudo systemctl enable openflight
sudo systemctl start openflight
```

Management:

```bash
sudo systemctl status openflight --no-pager   # Check status
journalctl -u openflight -f                   # View logs
sudo systemctl stop openflight                # Stop
sudo systemctl restart openflight             # Restart
sudo systemctl disable openflight             # Disable auto-start
```

To modify the service:

```bash
sudo nano /etc/systemd/system/openflight.service
sudo systemctl daemon-reload
sudo systemctl restart openflight
```

</details>

## Running OpenFlight

### Kiosk Mode (Fullscreen — Recommended)

```bash
./scripts/start-kiosk.sh        # Default: rolling buffer + sound trigger
./scripts/start-kiosk.sh --mock # Mock mode (no hardware needed)
```

Use the [IWR6843 startup steps](../iwr6843/verify.md#start-openflight) or
[Legacy K-LD7 Setup](../legacy/index.md) for angle-radar startup commands.

### Manual Start

```bash
openflight-server                # With radar
openflight-server --mock         # No hardware
```

Then open `http://localhost:8080`.

### Running Over SSH

```bash
DISPLAY=:0 ./scripts/start-kiosk.sh
```

## Observability (Grafana Cloud)

OpenFlight can ship session logs to Grafana Cloud for long-term analysis.

```bash
sudo ./scripts/setup/setup_alloy.sh
sudo vim /etc/alloy/credentials.env
```

See [observability.md](../using/observability.md) for full setup and LogQL queries.

## Troubleshooting

### Radar Not Detected

```bash
uv run python scripts/hardware-test/diagnose.py

# OPS243 connected through the Pi GPIO UART
uv run python scripts/hardware-test/diagnose.py --ops-port /dev/ttyAMA0
```

### Sound Trigger Not Working

See the [Sound Trigger Wiring Guide — Troubleshooting](../build/sound-trigger.md#troubleshooting).

### K-LD7 Not Connecting

```bash
# Check the device mapping
./scripts/setup/setup_kld7_devices.sh --show

# Test standalone
uv run python scripts/hardware-test/test_kld7.py
```

If the mapping is missing or points at the wrong radar, re-run the wizard:
`./scripts/setup/setup_kld7_devices.sh`. Look for `[KLD7] Connected on
/dev/ttyUSB...` in the server logs. See [K-LD7 Troubleshooting](../legacy/troubleshooting.md)
for "Wrong length reply" and other connection issues.

### Kiosk Window Closes Seconds After Loading

If the UI appears and then vanishes with `GPU process launch failed`,
`Failed to send GetTerminationStatus message to zygote`, and finally
`GPU process isn't usable. Goodbye.` in the terminal, something outside the
window killed Electron's helper processes. The usual culprit is a second
copy of `start-kiosk.sh`, typically a failing boot service restarting in a
loop while you launch by hand:

```bash
sudo systemctl status openflight --no-pager   # "activating (auto-restart)" = looping
journalctl -u openflight -n 40 --no-pager     # the recovery hint is printed here
```

Fix whatever the journal reports, or `sudo systemctl disable openflight` if
you launch from the desktop instead. Current launchers refuse to start while
another instance holds `/tmp/openflight-kiosk-<port>.lock` (exit code 3) and
only ever stop the browser they started, so an old unit file is the one thing
left to update: re-copy `scripts/setup/openflight.service` as shown in
[Auto-Start on Boot](#auto-start-on-boot).

### Service Won't Start

```bash
journalctl -u openflight --no-pager -n 50

# If service is masked
sudo systemctl unmask openflight
sudo cp ~/openflight/scripts/setup/openflight.service /etc/systemd/system/
sudo systemctl daemon-reload
sudo systemctl enable openflight
```

### Slow UI Updates

Check for WebSocket instability:
```bash
journalctl -u openflight -f
```

Look for "Client disconnected/connected" messages.

### Display Issues Over SSH

Use `DISPLAY=:0` before commands that need the Pi's display.

## Useful Commands

```bash
./scripts/setup/setup.sh --deps-only                              # Dependencies only
./scripts/start-kiosk.sh --port 3000                              # Custom web port
uv run python scripts/hardware-test/test_rolling_buffer_persist.py --test
uv run python scripts/hardware-test/test_sound_trigger_hardware.py
uv run pytest tests/ -v
```

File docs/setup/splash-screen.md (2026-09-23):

# Startup Splash Screen

OpenFlight can open a local splash screen immediately after a kiosk launch so
the operator can see that a desktop tap was accepted while software and radar
hardware initialize. Enable it with `--startup-splash`:

```bash
scripts/start-kiosk.sh --startup-splash
```

The splash is opt-in. Without the flag, `scripts/start-kiosk.sh` retains its
existing startup behavior.

OpenFlight starting the server and TI radar

## What It Shows

The component list is created from the active startup configuration before the
browser opens. OpenFlight server and the OPS radar are always first. Optional
hardware appears only when its corresponding command-line option is enabled.

| State | Meaning |
|---|---|
| Waiting | Configured, but its initialization step has not started |
| Starting | OpenFlight is actively initializing the component |
| Ready | Initialization completed successfully |
| Skipped | An optional component was unavailable and startup can continue |
| Error | Startup stopped and the recovery panel explains the next action |

The display order is intentionally independent of initialization order. The
existing synchronous hardware startup remains unchanged; the splash only makes
its boundaries visible.

When the OpenFlight server responds, the same Chromium window automatically
loads the main UI. The splash and its status endpoint bind only to loopback and
do not require internet access.

## Recommended Raspberry Pi Launcher

Most users can continue running `scripts/start-kiosk.sh` directly. A user-local
wrapper is recommended for a touchscreen installation because it can preserve
that Pi's device paths, measured geometry, camera calibration, and optional
hardware flags without placing machine-specific values in Git.

Install the example wrapper and terminal-free desktop entry:

```bash
cd ~/openflight
scripts/setup/install_desktop_launcher.sh
```

The installer derives an installation name from the checkout folder. The
standard `~/openflight` checkout uses `~/run-openflight.sh` and
`~/Desktop/OpenFlight.desktop`. An `~/openflight-startup-splash` checkout uses
`~/run-openflight-startup-splash.sh` and
`~/Desktop/OpenFlight-startup-splash.desktop`, displayed as
**OpenFlight (startup-splash)**.

The installer:

- Creates the checkout-specific wrapper from
  `scripts/setup/run-openflight.example.sh` only when it is absent.
- Records the checkout's absolute path in that wrapper while retaining
  `OPENFLIGHT_DIR` as an override.
- Preserves an existing checkout-specific wrapper on subsequent runs.
- Preserves an existing desktop entry unless replacement is explicit.
- Backs up the existing entry before an explicit replacement.
- Uses `Terminal=false` and does not invoke `lxterminal`.
- Makes the launcher executable and asks the Pi desktop to trust it.
- Points the desktop entry at the local wrapper rather than directly at the
  repository startup script.

Edit the reported local wrapper after its first installation. For the standard
checkout:

```bash
nano ~/run-openflight.sh
```

Add only the options for hardware installed on that Pi. For example:

```bash
openflight_args=(
    # --debug  # Uncomment to enable debug logging.
    --startup-splash
    --ballistics
    # --calculated-spin  # Replaces measured OPS spin with a kinematic estimate.
    --iwr6843
    --iwr6843-port /dev/serial/by-id/REPLACE_WITH_TI_SERIAL_ID
    --iwr6843-tee-m 1.372
    --iwr6843-net-m 4.064
    --iwr6843-tilt-deg 5.5
    --iwr6843-radar-height-m 0.229
    --iwr6843-ball-height-m 0.021
    --battery geekworm
)
```

`--calculated-spin` is intentionally commented out because it replaces OPS
spin with an opt-in kinematic estimate whenever a measured launch angle is
available. Enable it only when that behavior is desired.

The geometry above is an example, not a default. Follow the
[IWR6843 mounting guide](../iwr6843/mounting.md#measure-the-geometry) and enter the
measurements from the actual installation.

The example wrapper also holds a per-user launch lock. Repeated taps exit
without creating another process that could compete for the OPS, TI, camera, or
GPIO hardware.

## Updating An Existing Pi

After pulling a version that includes the splash:

```bash
cd ~/openflight
git pull
uv sync
scripts/setup/install_desktop_launcher.sh
```

If that checkout's desktop filename already exists, the final command reports
the collision and asks whether to replace it. Press Enter or answer `n` to
preserve the existing entry. Answer `y` only after reviewing it.

An approved replacement creates a timestamped backup beside the original. The
installer always preserves that checkout's local wrapper. No reboot is
required. Close an existing OpenFlight session first, then launch the refreshed
desktop icon.

If this pull is the first that launches **Electron** instead of system
Chromium, browser-local settings (units, theme, language, pinned Live metric)
and Shots validation notes do not migrate. Export **Export CSV** on the Shots
tab while Chromium is still the kiosk, then re-set preferences after Electron
starts. See [Electron Kiosk Shell](../electron-kiosk-shell.md#browser-local-state-breaking-on-first-electron-launch).
If Node is still 20 or the Pi is offline, startup keeps using Chromium until
Electron can be installed.

Raspberry Pi desktop settings determine whether icons require a single click or
a double click. The installer removes the separate “execute or execute in
terminal” choice; it does not change the user's global file-manager click
preference.

### Optional Faster Repeat Launches

`start-kiosk.sh` normally lets `uv` synchronize the environment, which makes an
updated checkout safe to launch. After running `uv sync`, a local wrapper may
skip that repeated work:

```bash
export OPENFLIGHT_UV_RUN_ARGS=--no-sync
```

Run `uv sync` again after pulling a dependency change. Camera installations
that rely on Raspberry Pi OS's system Picamera2 package may also require the
following local setting:

```bash
export UV_PYTHON=/usr/bin/python3
```

Do not add `GPIOZERO_PIN_FACTORY=lgpio`. OpenFlight selects the Raspberry Pi 5
GPIO chip explicitly; the environment override enters gpiozero's broken
auto-detection path instead.

## Startup Errors

The error screen identifies the component, gives the shortest known recovery
action, and retains the terminal-log location for diagnosis.

| Failure | Operator guidance |
|---|---|
| OPS unavailable | Check OPS USB and power connections, then relaunch |
| TI unavailable | Check TI USB and power connections, then relaunch |
| TI firmware wedged | Press RESET on the TI radar, then relaunch |
| Server preparation or timeout | Review the displayed terminal-log path |

| OPS unavailable | TI firmware wedged |
|---|---|
| OPS radar startup failure | TI radar reset guidance |

Select **Return to desktop** after a failure. This dismisses the error state and
releases the launch lock before the next attempt.

## Troubleshooting The Desktop Entry

### A Terminal Still Opens

Refresh the generated desktop entry:

```bash
cd ~/openflight
scripts/setup/install_desktop_launcher.sh
grep -E '^(Exec|Terminal|StartupNotify)=' ~/Desktop/OpenFlight.desktop
```

The paths above are for the standard checkout. For an alternate checkout, use
the suffixed filenames reported by the installer.

Answer `y` only after reviewing the existing desktop entry. Its timestamped
backup remains beside the new file. The new entry should report
`Terminal=false`, `StartupNotify=false`, and an `Exec` line that calls the local
`run-openflight.sh` through Bash without `lxterminal`.

### The Desktop Still Asks How To Open The File

Run the installer from the logged-in Pi desktop session so `gio` can set the
desktop trust metadata. The file must also remain executable:

```bash
chmod +x ~/run-openflight.sh ~/Desktop/OpenFlight.desktop
gio set ~/Desktop/OpenFlight.desktop metadata::trusted true
```

### Tapping Appears To Do Nothing

Another OpenFlight launcher may still hold the shared lock. Dismiss any visible
startup error with **Return to desktop**. If no UI is visible, inspect the
running processes and logs:

```bash
pgrep -af 'openflight-server|startup_splash_server'
ls -lt ~/openflight_sessions/terminal_logs | head
```

### Duplicate Desktop Icons

Multiple generated icons are expected when the Pi has multiple OpenFlight
checkouts; their suffixes identify the target folder. Move only obsolete or
legacy entries to a backup directory. Do not rename a generated entry without
also checking its `Exec` target.

## Promotion And Rollback

The splash remains controlled by one option in that checkout's local wrapper:

- **Promote:** keep `--startup-splash` in the checkout-specific wrapper.
- **Roll back:** remove only `--startup-splash`; hardware arguments and the
  terminal-free desktop entry continue to work.
- **Restore a customized launcher:** copy back the user's backup of
  the checkout-specific wrapper, then rerun `install_desktop_launcher.sh`.
- **Restore a desktop entry:** copy the desired timestamped
  backup back to that checkout's desktop filename.

The Raspberry Pi field pass covered successful OPS/TI/power startup, unplugged
OPS and TI failures, a wedged TI firmware failure, repeated desktop taps,
failure dismissal, and relaunch. The splash remains feature-gated so a rollout
does not require changing the underlying hardware initialization sequence.

## Maintainer Verification

Run the focused contracts with:

```bash
uv run pytest tests/test_desktop_launcher.py tests/test_start_kiosk.py \
  tests/test_startup_splash_server.py tests/test_startup_status.py -v
bash -n scripts/setup/run-openflight.example.sh \
  scripts/setup/install_desktop_launcher.sh scripts/start-kiosk.sh
```

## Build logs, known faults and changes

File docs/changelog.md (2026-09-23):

# Changelog

All notable changes to this project will be documented in this file.

The format is based on [Keep a Changelog](https://keepachangelog.com/en/1.1.0/),
and this project adheres to [Semantic Versioning](https://semver.org/spec/v2.0.0.html).

## [Unreleased]

### Changed
- **Chromium fallback is reachable during Electron upgrades.** If `ui/dist`
  already exists, a missing Electron install no longer requires Node 22.12 and
  a successful `npm install` before the kiosk can start. Old Node or a failed
  install warns and continues to system Chromium. A missing UI still requires
  Node 22.12+ and a successful build.
- **First switch from Chromium to Electron resets browser-local UI state.**
  Electron persists its own session under `~/.config/openflight-ui` (Linux),
  not the system Chromium profile. Units, language, theme, pinned Live metric,
  and validation annotations in `localStorage` do not carry over. Export the
  Shots CSV on Chromium before switching. Profiles and shot logs are
  server-owned and unaffected. See
  [Electron Kiosk Shell](electron-kiosk-shell.md#browser-local-state-breaking-on-first-electron-launch).

### Fixed
- **A crash-looping boot service no longer kills the desktop kiosk.** Every
  launcher exit ran a `pkill` that matched the Electron binary path, so an
  `openflight.service` that failed at startup (for example because systemd's
  PATH hides `~/.local/bin/uv`) restarted every 5 s and killed whichever
  kiosk was on screen; Chromium then died with "GPU process isn't usable.
  Goodbye." `start-kiosk.sh` now launches the browser in its own process
  group and stops only that group (`scripts/kiosk-browser.sh`), refuses to
  start while another instance holds `/tmp/openflight-kiosk-<port>.lock`
  (exit 3, `OPENFLIGHT_KIOSK_LOCK_FILE` overrides the path), finds `uv` in
  `~/.local/bin` / `~/.cargo/bin` when PATH omits them, and prints the
  recovery hint to the terminal and journal. The unit file stops retrying
  after five failures in five minutes and never retries exit 3. Re-copy
  `scripts/setup/openflight.service` (or rerun `scripts/setup/setup.sh`) on
  existing Pis to pick up the unit changes.
- **Kiosk startup no longer rebuilds the UI after Electron has already launched.**
  `ensure_kiosk_ui` now runs before the splash browser. The helper is also
  stored with Unix line endings so a Windows checkout cannot make `ui/dist`
  look missing (a CR in the path) and run `npm install` over a live Electron
  GPU process.
- **On-screen keyboard for profile names.** Adding or renaming a profile on the
  Pi kiosk now shows a full-screen keyboard. Chromium in `--kiosk` mode does not
  surface a system keyboard, so the native text field was unusable on the
  touchscreen.
- **Clear-session confirmation is a modal again.** The overlay, scrim, and
  centered dialog styles were missing after the class-name rename, so at the
  800×480 kiosk size the prompt rendered as inline page content.
- **Attack angle no longer inflated by 1/cos(club path).** The camera club
  delivery divided vertical speed by the forward component alone instead of the
  full horizontal speed, overstating attack angle on any shot with club path.

### Added
- **Electron kiosk shell.** `scripts/start-kiosk.sh` now opens the UI in a pinned
  Electron window (`electron@44`) instead of whichever system browser happens to
  be installed. Chromium remains a fallback if Electron is not installed (including
  when Node is older than 22.12 or `npm install` fails and `ui/dist` already
  exists). Installing Electron needs **Node.js 22.12 or newer**. See
  [Electron Kiosk Shell](electron-kiosk-shell.md).
- **PAR-TEE connector.** `"type": "partee"` in `config/sim.json` streams shots
  to the [PAR-TEE](https://playpartee.com) iPhone app over OpenConnect V1 on the
  phone's Wi-Fi address (port 921 by default). Same shared codec as GSPro and
  OpenGolfSim; the header pill and "Sent to" panel read PAR-TEE.
- **Profiles replace players.** Shots are now attributed to a server-owned profile
  (a person *or* a place) with a stable id, persisted to
  `~/.config/openflight/profiles.json` (override with `OPENFLIGHT_PROFILES_PATH`
  or `--profiles-path`). Profiles can be renamed without orphaning their shots.
  Removing a profile is refused while it still has session rows. The socket
  exposes a single authoritative `profiles` snapshot plus
  `set_active_profile` / `add_profile` / `rename_profile` / `remove_profile`.
  Breaking: `set_player` / `player_changed` are gone, `Shot.player_name` is replaced
  by `profile_id` + `profile_name`, and existing browser-local player rosters are
  discarded.
- **Automatic OV9281 exposure control.** High-speed camera capture now measures
  the impact area every five seconds, restores the last known-good setting at
  startup, and selects a shutter/gain combination that preserves club contrast
  without excessive clipping or motion blur. Large lighting changes re-enter
  fast convergence while smaller changes require confirmation. Camera-derived
  shot analysis is withheld when lighting is unsuitable, but radar processing
  and shot display continue normally with an operator-facing lighting warning.
- **Instrument-panel kiosk UI.** The dashboard is a tabbed shell (Live, Stats,
  Shots, Camera, Profiles, Debug) instead of the previous stacked shot and stats
  views. Tap a Live metric to pin it top-left while keeping all ten metrics
  visible. The footer logo opens units, dark/light theme, language, simulator,
  and ball-detection status; a persistent footer power button opens the shutdown
  confirmation. Club (or training implement) selection is a Live header action.
  See the [UI README](https://github.com/jewbetcha/openflight/blob/main/ui/README.md).
- **Kiosk languages.** English, Spanish, French, and Portuguese. Choice is
  stored in `localStorage` (`openflight.locale:v1`).
- **Dark and light themes.** Toggle in the footer menu; stored as
  `openflight.theme` (default dark).
- **Synchronized OV9281 high-speed camera capture.** OpenFlight can now retain
  pre- and post-impact camera frames from the shared sound trigger, align them
  with OPS243 and IWR6843 captures, and use camera-assisted or camera-only
  fallbacks for horizontal launch, club path, and angle of attack. The Camera
  tab adds live alignment, crop, orientation, and lighting controls while the
  rolling buffer remains armed. See [OV9281 Camera](camera/README.md).
- **On-demand camera shot replay.** Camera-backed shots can open a 60 FPS
  slow-motion impact player from Live or Shots, with touch controls, scrubbing,
  and a trigger-frame impact marker. MP4 conversion starts only after a manual
  Replay selection, caches the result beside the raw capture, and reports
  retryable preparation or playback failures without affecting shot results.
- **Battery and external-power status for Raspberry Pi UPS boards.** OpenFlight
  can now display charging state and battery percentage, issue dismissible 20%
  and 10% warnings while discharging, and record throttled power telemetry in
  session logs. Enable the initial Geekworm X1202/X1206 provider with
  `--battery geekworm`; monitoring remains disabled when no provider is
  selected. The accompanying Pi setup installs native Linux power-supply
  telemetry and optional taskbar capacity support without enabling automatic
  shutdown or charging control. See [Battery Monitoring](using/battery.md).
- **System Prerequisites:** Documented missing binary dependencies (`swig`, `liblgpio-dev`, `python3-dev`) required prior to executing `./scripts/setup/setup.sh`.
- **Environment Reload Guidance:** Added instructions for reloading terminal environment variables (`source ~/.bashrc`) when installed dependencies or scripts (`setup.sh`, `start-kiosk.sh`) are not recognized in the current terminal session.
- **Configurable IWR6843 capture compression.** One firmware image can now
  switch at runtime between the recommended 24-frame, 3 ms, 53-bin IQ16
  profile and an advanced 36-frame, 2 ms, 32-bin IQ8 profile. Both retain the
  same 72 ms shot movie and all 3 TX x 4 RX channels. Per-frame range windows,
  timing, and IQ8 scales are carried in the dump so offline and live processing
  use the actual capture geometry. The dense profile uses a sparse scale
  preview to sustain the 2 ms HWA rearm budget and exposes missed frames,
  overruns, and clipped components through firmware `stats`.
- **OPS243 over the Raspberry Pi GPIO UART.** The radar can now run on the J3
  header instead of USB, which frees the Pi's USB power budget for the TI angle
  radar. Baud is the real wire rate on that transport and the factory default of
  19,200 would stretch a 40.6KB dump to 21 seconds, so the driver probes for the
  rate the board is actually using and raises it to 230,400 (`I5`), bringing a
  dump down to ~1.8 seconds. Every dump timeout now scales with the negotiated
  rate, so a link that settles low runs slowly instead of truncating captures.
  Pass `--radar-port /dev/ttyAMA0` (and optionally `--ops-baud`); USB behaviour
  is unchanged. `diagnose.py --ops-port` adds a preflight for the three
  UART-only failures that all look like an unresponsive radar — missing device
  node, a login console holding the port, and the OPS USB cable still plugged in
  (which silences the UART). See
  [Moving the OPS243 from USB to the Pi GPIO UART](build/ops243-uart.md).
- **Flash IWR6843 firmware directly from a Raspberry Pi.** Contributors no
  longer need an Intel Mac, UniFlash, or TI Cloud Agent for routine firmware
  updates. The guided terminal workflow verifies the image hash, offers a
  non-destructive bootloader probe, erases the existing image, transfers the
  replacement in acknowledged chunks, and requires the radar's ROM bootloader
  to verify the completed image. The current IWR6843LEVM still requires its
  physical flash-mode switch and reset button.
- **Experimental three-transmitter capture for horizontal launch direction.**
  The TX2 firmware variant captures all three transmitters while retaining the
  TX1/TX3 vertical array, giving the offline and live pipelines the antenna
  diversity needed to begin measuring left/right start direction.
- **On-chip range snapshots for smaller IWR6843 shot captures.** The radar uses
  its hardware accelerator and EDMA to retain 53 selected complex range-FFT
  bins in moving early, middle, and late windows instead of every raw ADC
  sample. The production ring keeps 18 frames at 4 ms spacing in a 549,542-byte
  dump while preserving vertical and horizontal processing inputs.
- **`--kld7` now delivers the full launch-angle pipeline by default.** Enabling
  the K-LD7 radars turns on the **two-ray multipath vertical launch-angle
  estimator** (per-frame demodulation that separates the ball from its floor
  reflection to recover true elevation instead of averaging across the
  multipath) plus the **ball-speed cosine correction** (OPS radial → true
  speed). Each shot is graded into a tour-derived Tier-1/Tier-2 confidence with
  a tour-average boost for suppressed reads; measurements that clear the
  physics guard but trip a soft consistency guard are shown as **marginal
  (one-dot) confidence** rather than silently replaced by the club estimate.
  Far-net flights are de-aliased past the FSK range wrap (`--net-distance`).
- `--kld7-mount-tilt` is **required** with `--kld7` (measure with a phone
  inclinometer — no safe default). `--kld7-angle-offset` defaults to the
  calibrated `1.5`.
- `--calculated-spin` (opt-in, off by default): replaces radar spin with the
  kinematic estimate `170·v·sin(LA)^1.2`; the measured value is retained in
  `spin_rpm_measured` for scoring.
- `--kld7-vertical-raw` test mode surfaces the raw radar angle for every shot
  (all display guards bypassed).
- **Club path from the IWR6843's pre-impact frames.** `Shot.club_path_deg` has
  been wired end to end since the K-LD7 era but unpopulated since that radar
  was deprecated. It now comes from the six pre-impact frames the L3-dump
  firmware already retains. The estimator fits `x(t)` and `y(t)` in Cartesian
  coordinates and reports `path = atan2(v_y, v_x)`; absolute azimuth enters
  additively rather than cancelling out, so a constant per-element phase error
  from the shipped array calibration (measured on a different board) shifts
  the reported path by a constant rather than the estimator itself — which is
  what `--iwr6843-azimuth-offset-deg` is for. Measured on a first-principles
  fixture across ±12°, absolute error grows with angle (0.034° at 4° to
  0.303° at −12°, roughly symmetric), so it separates deliberate in-to-out
  from out-to-in swings but does not support degree-level claims. Ships
  experimental; validate with `scripts/iwr6843/club_path_report.py` before
  trusting it.

### Changed
- Club physics and simulation defaults now lives in one immutable registry
- Core server, session logging, kiosk startup, and UI code now share canonical
  shot/session helpers and omit redundant compatibility paths.
- Session JSONL format version is now 2 after consolidating trigger and shot
  entries and removing obsolete entry types.
- Display mode (`/display`) now uses the same metric cards and theme tokens as
  the kiosk Live view.
- The vertical estimator is now a fixed cascade (two_ray → geometry →
  single-frame geometry → naive); it is no longer user-selectable. Launch-angle
  source and confidence semantics changed accordingly.

### Removed
- Deprecated integrated-camera detection, obsolete K-LD7 experiment/replay
  tooling, unused session-log writers, and their redundant tests and controls.
- `--kld7-vertical-estimator` (estimator is a fixed cascade), `--kld7-geometry`
  (kiosk preset), and `--ball-speed-cosine-correction` (folded into `--kld7`).
  `--kld7-bypass-vertical-gate` renamed to `--kld7-vertical-raw`.

### Fixed
- Kiosk startup no longer exits when the optional Alloy service is unavailable,
  and it rebuilds the UI bundle before launching the server.
- **Graceful IWR6843 shutdown.** Kiosk shutdown now asks the server to finish
  hardware cleanup before escalating to process signals. An active TI dump is
  allowed to complete, capture firmware is stopped and verified inactive, and
  the serial port is then closed. This prevents an interrupted L3 transfer or
  failed GPIO setup from leaving the radar unresponsive on the next startup.
- **Raspberry Pi 5 & OS Compatibility:** Updated UART configuration documentation to support Debian Bookworm and Raspberry Pi 5 hardware using `dtparam=uart0=on` alongside legacy `enable_uart=1`.
- **UART Diagnostic Commands:** Simplified UART verification instructions in `docs/iwr6843/README.md` and `docs/ops243-uart-migration.md` using `grep -E` to check for both legacy and modern device-tree parameters simultaneously across config paths.
- Session logging: serialize all access to the session JSONL file with a
  lock. The `log_*` methods are called concurrently from the OPS243
  capture thread, the K-LD7 stream thread, and Flask-SocketIO handlers;
  without synchronization, large entries (e.g. `rolling_buffer_capture`
  with 2×4096 samples) could interleave and corrupt JSONL lines, and a
  write could race `end_session()` closing the file (`AttributeError` /
  `ValueError: I/O operation on closed file`). Corrupt lines break the
  offline replay tooling that depends on these logs.
- IWR6843 runtime: the ball-estimate call passed a hardcoded
  `tdm_sign_policy="positive"` instead of the runtime's configurable field
  (the club-path fallback already honored the field, and offline replay
  plumbs a caller-supplied policy end to end). Any non-default policy
  silently produced different live-vs-replay answers for the same capture.
  Live behavior with the default is unchanged.
- **GPIO startup on a Raspberry Pi 5.** Anything using the sound-trigger GPIO —
  the IWR6843 capture monitor and the GPIO sound trigger — died with
  `BadPinFactory: Unable to load any default pin factory!`. The cause is
  upstream: gpiozero 2.0.1.post2 (the latest release) calls `os.path.exists`
  in its lgpio chip auto-detection without importing `os`, and that code path
  only runs on a Pi 5, so gpiozero swallows the `NameError` and every remaining
  backend then fails for its own reason. OpenFlight now selects the lgpio
  factory itself with an explicit gpiochip, which skips the broken branch.
  `OPENFLIGHT_GPIO_CHIP` overrides the chip if a kernel update renumbers the
  header. Note that `GPIOZERO_PIN_FACTORY=lgpio` was never a workaround — it
  forces the same failing call.
- IWR6843 range-snapshot capture now freezes only at a completed ring boundary
  and correctly rearms the HWA/EDMA chain, preventing partial or one-shot-only
  captures during repeated shots.
- K-LD7 tracker: shots could silently lose their launch angle when the
  stream thread appended a frame while the shot path iterated the ring
  buffer (`snapshot_buffer` / `_radc_frames_for_extraction`). CPython
  raises `RuntimeError: deque mutated during iteration` for this, and
  the server's broad K-LD7 exception handler swallowed it, so the shot
  was reported without an angle and no error was visible. Buffer reads
  now copy under a lock; appends and resets take the same lock.
- **One collapsed channel no longer drags the launch angle down.** The vertical
  estimator averaged its two channel estimates unweighted. On a 0.229 m, 5.5°
  mount the `two8` channel collapsed to about 0° on five of six shots while
  `four4_path_tdm` read 15.3–22.0°, so five 7-irons that actually launched near
  17° were reported at 7–9°, each stamped with 0.95 confidence while
  `component_std_deg` sat at 8–10° in the log. Across a seven-shot session the
  plain mean read 10.9° with one channel collapsed; channel selection recovers
  18.3°. Channels that disagree beyond 8° now resolve to the better-supported
  one with reduced confidence; channels that agree are still averaged.
- **Launch-angle confidence is derived instead of hardcoded.** Both the vertical
  and horizontal angles reported a constant 0.95. The horizontal case computed
  HLCMF-v0 coherence, logged it, and then discarded it in favour of the
  constant, so five estimates whose own channels disagreed by 8–10° were
  presented as high confidence. Vertical confidence now follows channel
  agreement and corroboration, horizontal follows coherence, and `spin_axis_deg`
  gates on the horizontal leg rather than appearing the moment club path exists.
- **Track-span floor relaxed from 18 ms to 15 ms, and the span is now logged.**
  Recovers usable captures — one range session went from 6/7 accepted at a
  10.9° mean to 7/7 at 18.3°, and the 18 ms → 15 ms change is what recovered
  the seventh shot. The span is now recorded, since it was the gate rejecting
  most shots and was invisible without an offline replay.
- **A channel that measured nothing can no longer win the channel selection.**
  Objective curvature scored 0 both when a channel's minimum was genuinely
  flat and when its minimum sat on the edge of the −5° to 45° search grid —
  two different things, since an edge minimum means the true angle lies
  outside the searched range and a real launch above 45° pins a perfectly
  healthy channel there. Curvature now returns "no measurement" for an edge
  minimum, and such a channel takes no part in selection, in the spread
  comparison, or in the reported `component_std_deg`. When the channels
  disagree and none has positive curvature — all flat, all off-grid, or
  unscored — the shot is rejected as `rejected_no_conditioned_channel`
  instead of returning whichever channel came first in the dictionary, which
  was `two8`, the one that collapses.
- **The `fast_*` estimates no longer veto corroboration they cannot win.** All
  five components fed the agreement comparison while only the two channel
  models could be selected, so one `fast_*` outlier pushed the spread past
  the 8° gate and cut two channels agreeing to 0.4° down to a single channel
  flagged as uncorroborated and derated. They are diagnostic-only: still
  logged in `components_deg`, now excluded from the selection decision and
  from `component_std_deg`. Affects raw-ADC captures only — range-snapshot
  captures never computed the fast-time models.

### Known Limitations

Deferred pending a session paired with a reference instrument. See
[the IWR6843 operator guide](iwr6843/calibration.md#launch-angle-estimator-limitations).

- **The calibration tilt sweep cannot recommend a tilt.** It minimises
  `component_std_deg`, which is monotonic in tilt across the swept window, so
  its minimum lands on a window edge instead of the mount angle: on the
  2026-07-25 session, with the mount measured at 5.5°, a ±3° sweep returned
  2.5° on two shots and 8.5° on two others. Set tilt by physical measurement.
- **The curvature criterion is not scale-normalised.** `four4_path_tdm`'s
  objective range is 2–4× larger than `two8`'s, so most of the "3.7–10.7×
  sharper" margin is model scale — on one shot the true margin is 1.14×. It is
  validated as a degeneracy detector, not an accuracy ranker, and it is
  one-sided: a collapsed `four4_path_tdm` would likely still win.
- **Selecting is worse than averaging when both channels are healthy but
  disagree.** Monte Carlo at 6° of noise: 4.26° RMS averaging against 5.79°
  selecting, 7.93° on the disagreeing subset. The 8° gate's justification is a
  gap between one shot at 4.59° and six at 15.9–20.2°, from a single session,
  club, geometry and tilt.

### Changed
- Spin detection: drop the autocorrelation override branch. The autocorr
  peak inside the envelope search region often lands at minimum lag
  (~12000 RPM / upper rail) by spectral coincidence, which previously
  flipped legitimate mid-range FFT seam picks to the upper rail and got
  them rejected as bandpass-shoulder noise. The autocorr fallback still
  *confirms* the FFT pick when the two agree within 10%; disagreements
  are now logged for diagnostics but never replace the FFT result.
- Spin detection: lower `SPIN_SNR_MIN` from 3.0 → 2.5 so marginal but
  real seam tones are reported at low confidence instead of dropped.

### Added
- `scripts/analysis/replay_club_speed.py`: offline replay of a proposed
  MEDIAN club-speed picker against any session log. Builds the same
  candidate set the production picker uses, applies a 30 % magnitude
  floor, and reports the median speed for each `rolling_buffer_capture`
  alongside the originally logged (magnitude-pick) value, with smash
  factors as a physical sanity check. The script is exploratory and
  does not change production behaviour — it lets us inspect what a
  median-based picker would have produced before committing to a code
  change.
- `scripts/analysis/plot_spin_debug.py`: 4-panel diagnostic for a single
  `rolling_buffer_capture` (speed timeline, raw I/Q, bandpass envelope,
  envelope FFT spectrum) to inspect what the spin algorithm saw and why
  it accepted or rejected a shot.
- K-LD7 shot-correlation analysis workflow and theory writeup
  - `scripts/analyze_kld7.py --pair-shots` for offline club-to-ball pairing on `.pkl` captures
  - `docs/kld7-ball-detection-theory.md` with capture findings and detection rationale
- Persistent rolling buffer mode workaround for OPS243-A HOST_INT pin bug (per OmniPreSense)
  - `persist_rolling_buffer_mode()` method saves settings to flash memory
  - `test_rolling_buffer_persist.py` script for one-time radar setup and verification
  - Rolling buffer + sound trigger is now the default operating mode
- Grafana Alloy integration for shipping session logs to Grafana Cloud Loki
  - Setup script (`scripts/setup_alloy.sh`) and config (`config/alloy.alloy`)
  - Auto-starts with `start-kiosk.sh` when credentials are configured
  - Observability documentation with LogQL query examples
- Launch angle estimation from club type and ball speed (fallback when camera unavailable)
- Tunable Hough circle detection with all 5 parameters as CLI args (`--hough-param1`, `--hough-param2`, `--hough-min-radius`, `--hough-max-radius`, `--hough-min-dist`)
- Interactive `--tune` mode in `test_launch_angle.py` with live OpenCV trackbar sliders
- Mock mode now simulates realistic spin and launch angle data (TrackMan-based per-club averages)
- Sound trigger wiring guide with MOSFET circuit design (`docs/sound-trigger-wiring.md`)
- Camera integration with real-time ball detection in UI
- Ball detection indicator in header (shows detection status)
- Camera tab with live MJPEG stream and detection overlay
- Hough circle transform as default ball detector (replaces YOLO dependency)
- ByteTrack object tracking for persistent ball identification
- Club speed detection and smash factor calculation
- Rolling buffer mode for experimental spin rate detection
- Session logging to JSONL files (`~/openflight_sessions/`)
- I/Q streaming mode with FFT and 2D CFAR noise rejection
- `--mode rolling-buffer` flag for spin detection
- `--session-location` and `--log-dir` flags for session logging
- Roboflow API integration as optional detection backend
- YOLO performance tuning documentation for Raspberry Pi
- ONNX model export support for faster inference
- Threaded camera capture for improved FPS
- Rolling buffer spin detection documentation

### Changed
- K-LD7 launch-angle processing now uses OPS243 impact timestamps for live correlation
- K-LD7 ball-burst selection now prefers coherent far-target paths instead of averaging all far PDAT detections
- Live K-LD7 vertical launch angles now fall back to the existing club-and-speed estimate when the radar result is an obvious false positive
- Spin detection improved: Hann windowing, zero-padding to 256 points, band-limited search
- All shot metrics (spin, launch angle, club speed, carry) always shown in UI
- Shot logging unified — all metrics in single `shot_detected` entry
- Shot `mode` and `readings_data` are now proper dataclass fields (no more monkey-patching)
- Session logging enabled in mock mode for testing Alloy integration
- Default ball detection uses Hough circles instead of YOLO (no ML model required)
- Camera enabled by default in kiosk mode (use `--no-camera` to disable)
- Dropped Python 3.9 support (requires >=3.10)
- Updated Raspberry Pi setup guide with camera UI and observability instructions

## [0.2.0] - 2024-12-01

### Added
- Web UI with React frontend and Flask-SocketIO backend
- Real-time shot display with ball speed, carry distance, smash factor
- Session statistics view with per-club filtering
- Shot history with pagination
- Debug panel for radar tuning and raw readings
- Mock mode for development without hardware
- Kiosk mode script for Raspberry Pi deployment
- Systemd service for auto-start on boot
- Camera module for launch angle detection (experimental)
- Camera-based ball tracking for launch angle
- Club type selection (Driver through PW)

### Changed
- Migrated from CDM324/HB100 radar to OPS243-A
- Improved carry distance estimation model

## [0.1.0] - 2024-10-01

### Added
- Initial OPS243-A radar driver
- Basic launch monitor with shot detection
- CLI interface for monitoring shots
- Python API for integration
- Carry distance estimation based on ball speed

[Unreleased]: https://github.com/jewbetcha/openflight/compare/v0.2.0...HEAD
[0.2.0]: https://github.com/jewbetcha/openflight/compare/v0.1.0...v0.2.0
[0.1.0]: https://github.com/jewbetcha/openflight/releases/tag/v0.1.0

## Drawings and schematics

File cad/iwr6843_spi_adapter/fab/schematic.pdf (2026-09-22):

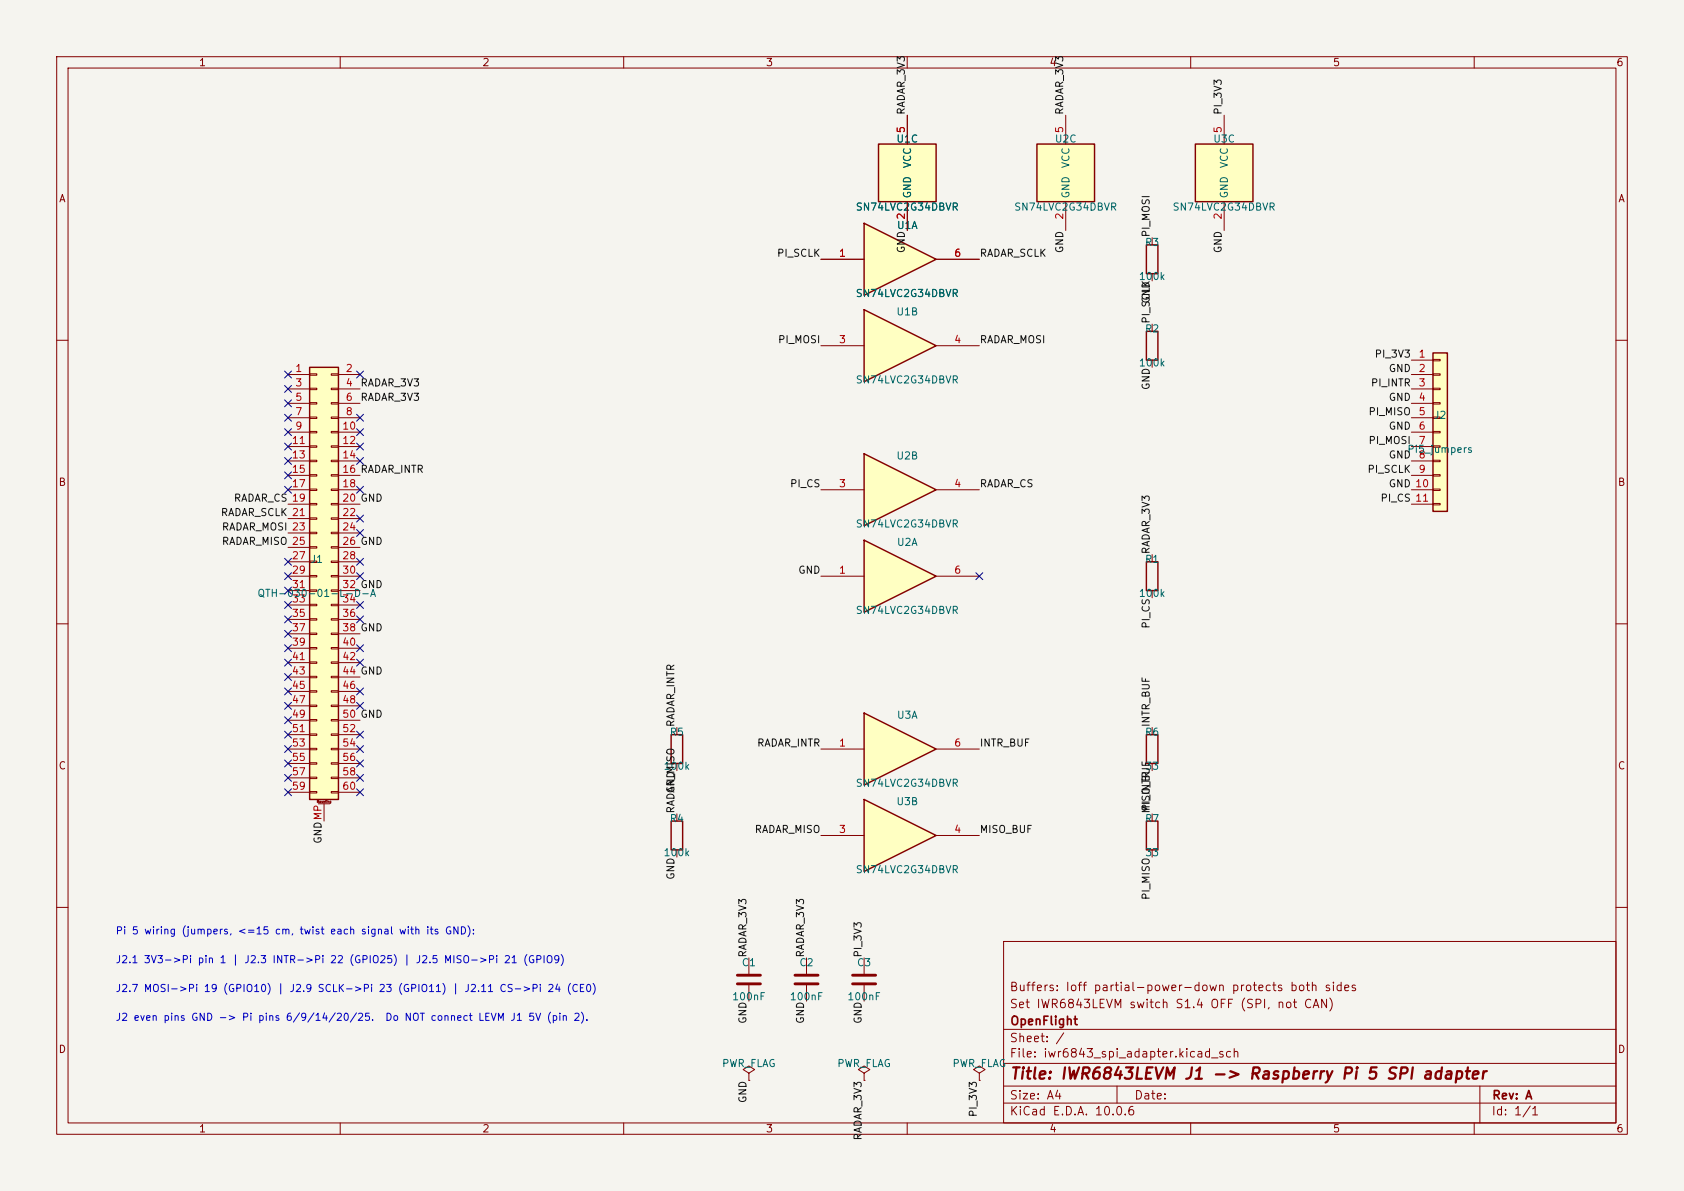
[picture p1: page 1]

Buffers: Ioff partial-power-down protects both sides C1

Set IWR6843LEVM switch S1.4 OFF (SPI, not CAN)
OpenFlight
Sheet: /
File: iwr6843_spi_adapter.kicad_sch
Title: IWR6843LEVM J1 -> Raspberry Pi 5 SPI adapter

Size: A4 | Rev: A
KiCad E.D.A. 10.0.6 | Id: 1/1

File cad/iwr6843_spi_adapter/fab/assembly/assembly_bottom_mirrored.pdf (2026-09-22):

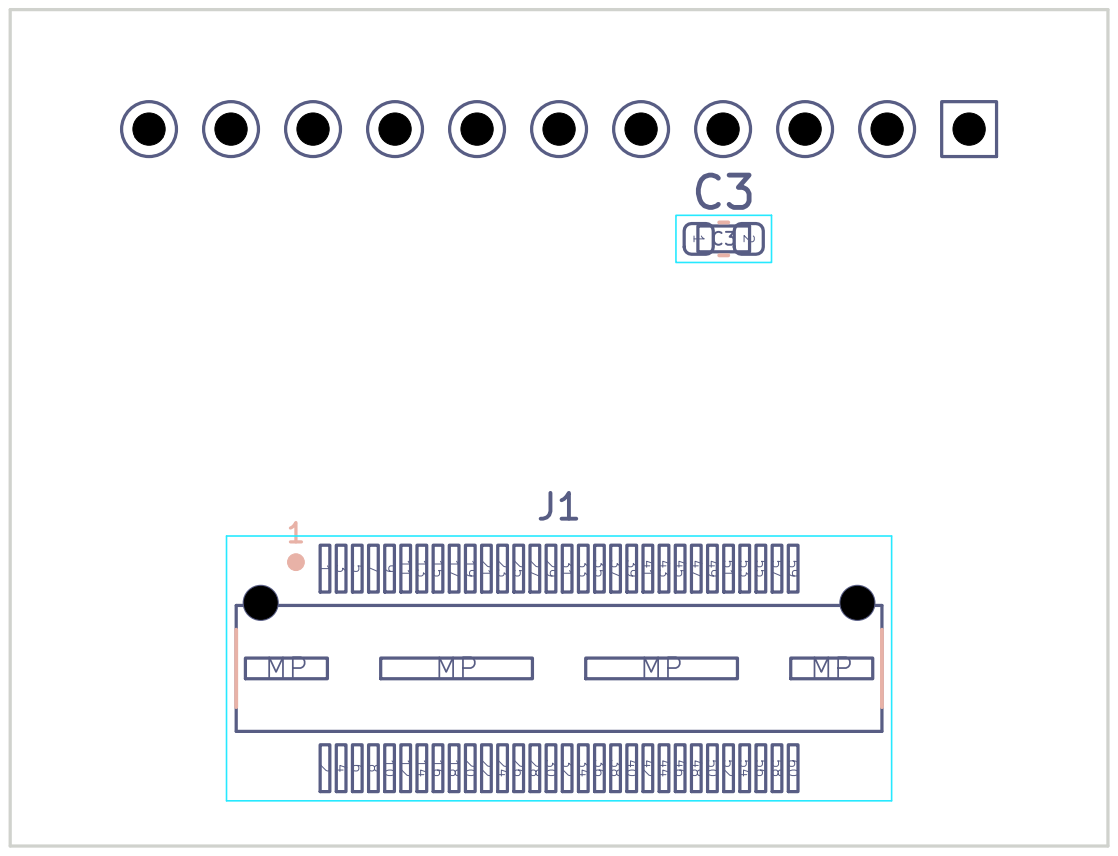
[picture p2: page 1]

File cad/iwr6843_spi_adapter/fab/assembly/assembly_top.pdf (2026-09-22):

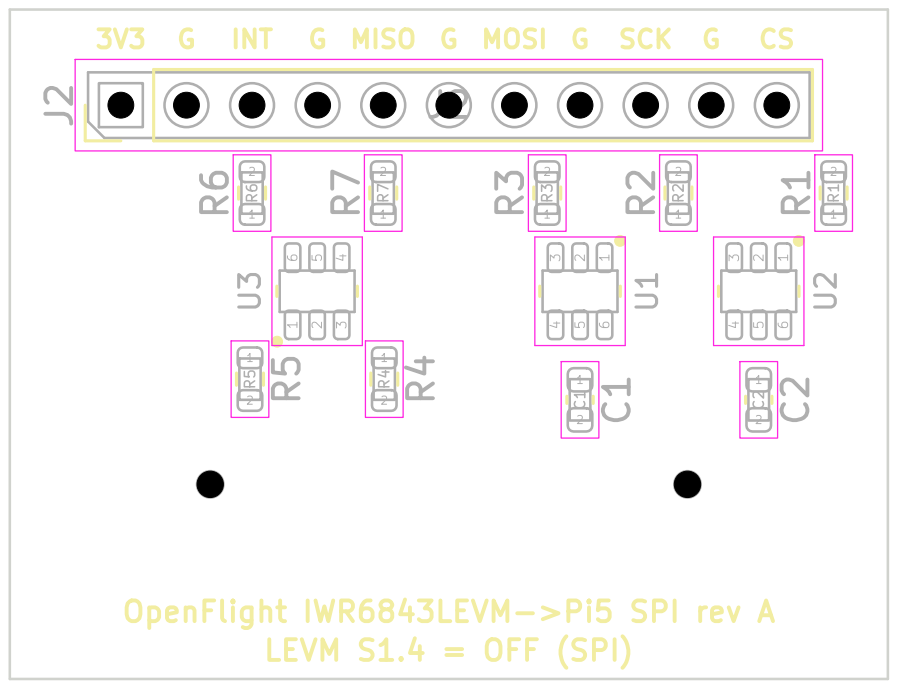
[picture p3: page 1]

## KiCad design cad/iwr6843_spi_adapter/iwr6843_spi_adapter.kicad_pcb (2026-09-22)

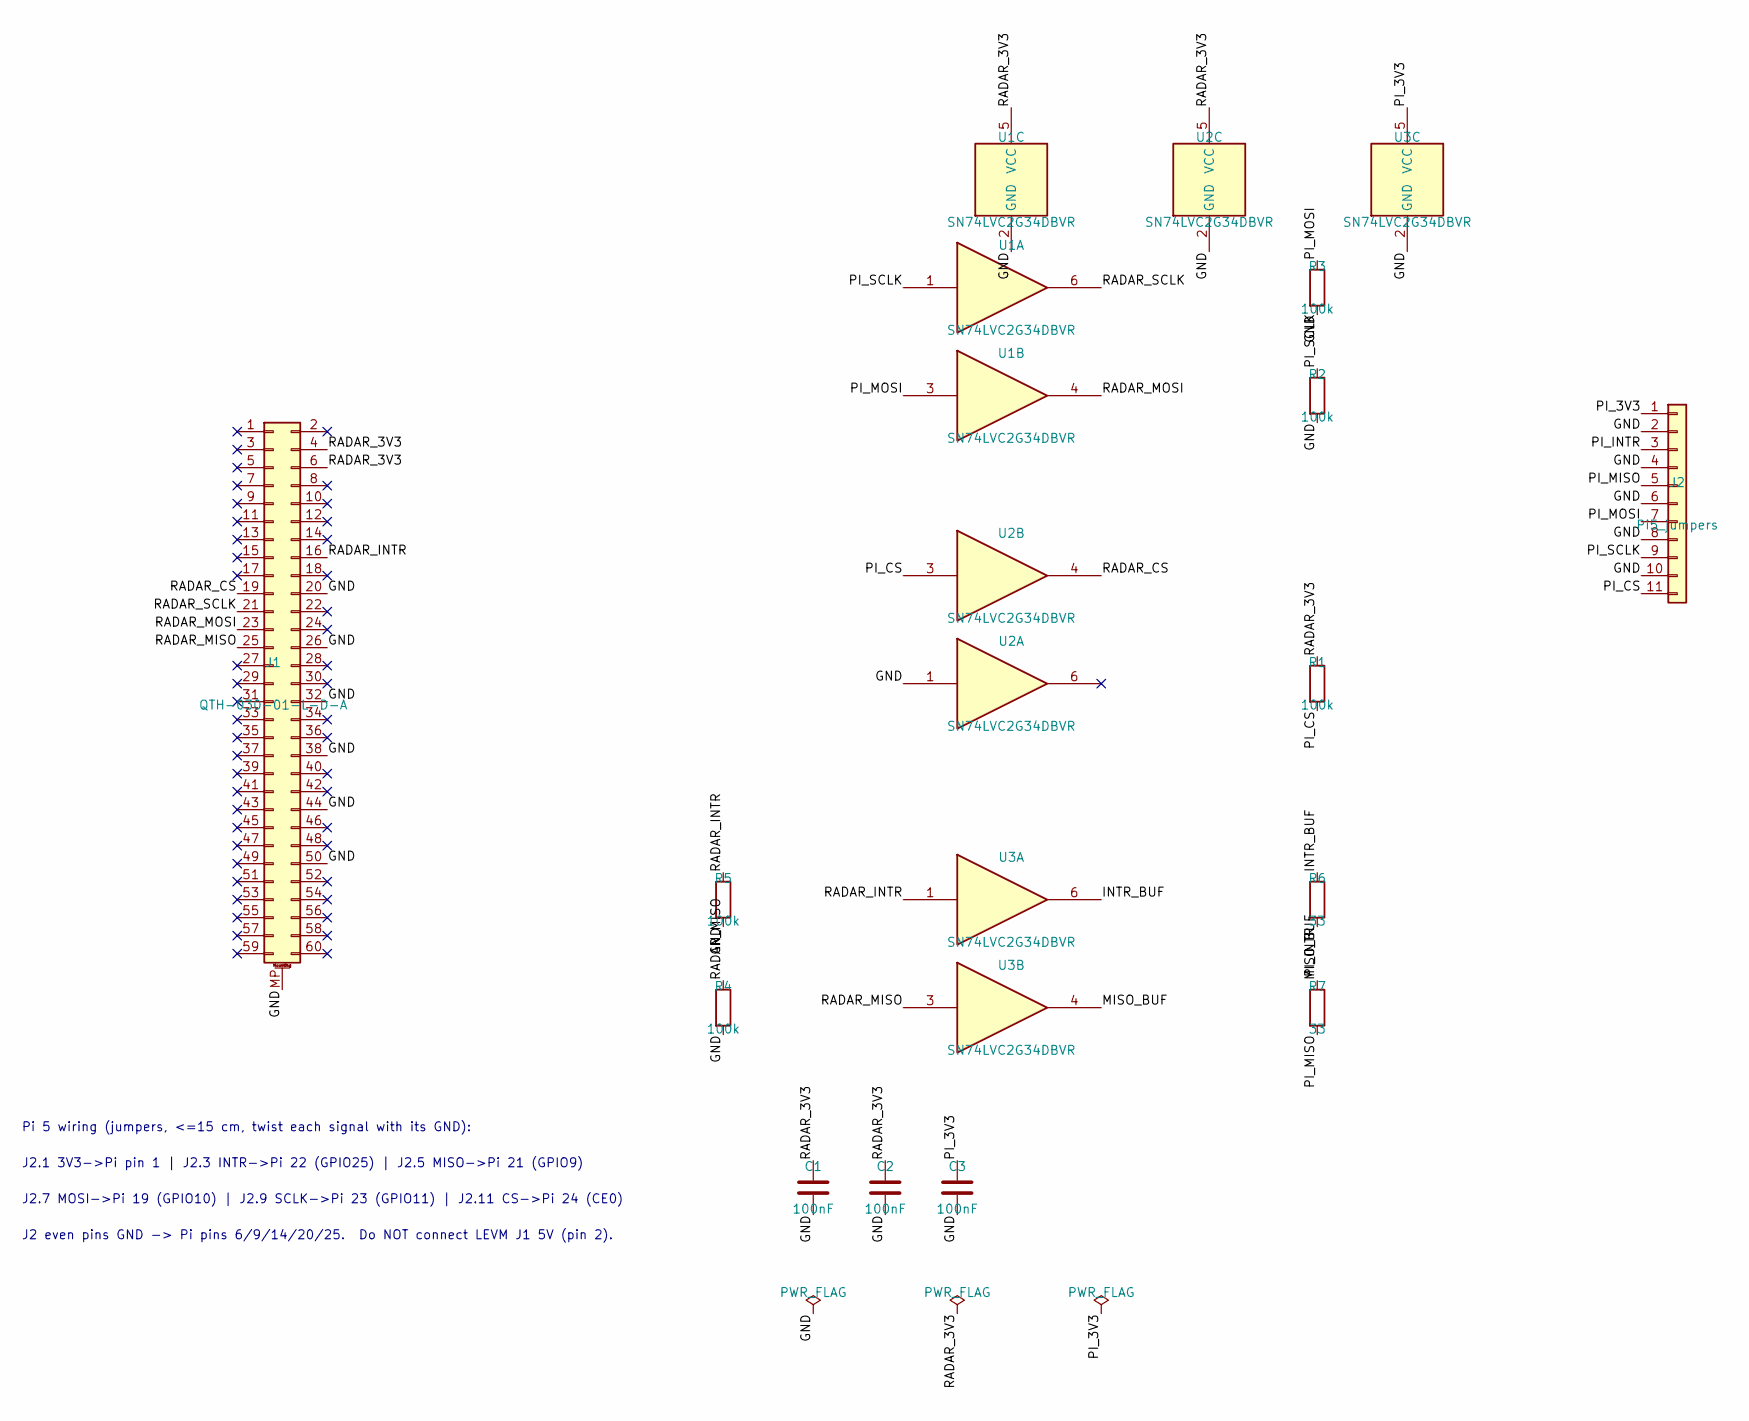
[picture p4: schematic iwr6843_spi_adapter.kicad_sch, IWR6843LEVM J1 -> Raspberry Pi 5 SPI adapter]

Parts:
C1, C2, C3: 100nF; C_0603_1608Metric; MPN CL10B104KB8NNNC
J1: QTH-030-01-L-D-A; Samtec_QTH-030-01-L-D-A; MPN QTH-030-01-L-D-A
J2: Pi5_jumpers; PinHeader_1x11_P2.54mm_Vertical
R1, R2, R3, R4, R5: 100k; R_0603_1608Metric; MPN RC0603FR-07100KL
R6, R7: 33; R_0603_1608Metric; MPN RC0603FR-0733RL
U1, U2, U3: SN74LVC2G34DBVR; TI_DBV0006A; MPN SN74LVC2G34DBVR

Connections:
/GND: C1.2, C2.2, C3.2, J1.20, J1.26, J1.32, J1.38, J1.44, J1.50, J1.MP (MountPin), J2.2, J2.4, J2.6, J2.8, J2.10, R2.2, R3.2, R4.2, R5.2, U1.2 (GND), U2.1, U2.2 (GND), U3.2 (GND)
/INTR_BUF: R6.1, U3.6
/MISO_BUF: R7.1, U3.4
/PI_3V3: C3.1, J2.1, U3.5 (VCC)
/PI_CS: J2.11, R1.2, U2.3
/PI_INTR: J2.3, R6.2
/PI_MISO: J2.5, R7.2
/PI_MOSI: J2.7, R3.1, U1.3
/PI_SCLK: J2.9, R2.1, U1.1
/RADAR_3V3: C1.1, C2.1, J1.4, J1.6, R1.1, U1.5 (VCC), U2.5 (VCC)
/RADAR_CS: J1.19, U2.4
/RADAR_INTR: J1.16, R5.1, U3.1
/RADAR_MISO: J1.25, R4.1, U3.3
/RADAR_MOSI: J1.23, U1.4
/RADAR_SCLK: J1.21, U1.6

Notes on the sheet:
Pi 5 wiring (jumpers, <=15 cm, twist each signal with its GND):
J2.1 3V3->Pi pin 1 | J2.3 INTR->Pi 22 (GPIO25) | J2.5 MISO->Pi 21 (GPIO9)
J2.7 MOSI->Pi 19 (GPIO10) | J2.9 SCLK->Pi 23 (GPIO11) | J2.11 CS->Pi 24 (CE0)
J2 even pins GND -> Pi pins 6/9/14/20/25. Do NOT connect LEVM J1 5V (pin 2).

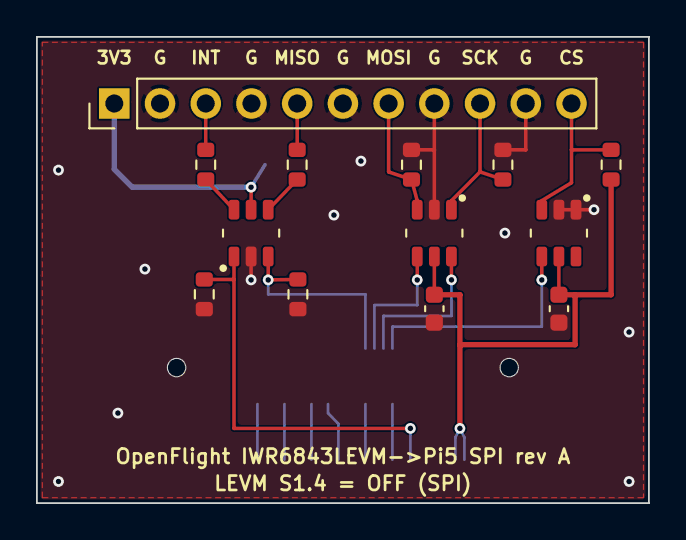
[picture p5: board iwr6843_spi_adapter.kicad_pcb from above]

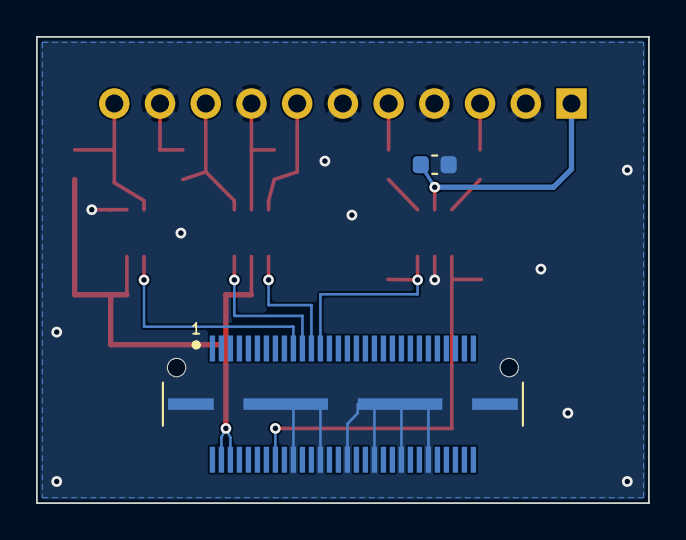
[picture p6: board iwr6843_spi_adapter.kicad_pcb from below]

Board: 2 copper layers, 34.0 x 25.9 mm, 15 parts (2 on the bottom side), 15 nets.

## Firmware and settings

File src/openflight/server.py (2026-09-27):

"""
WebSocket server for OpenFlight UI.

Provides real-time shot data to the web frontend via Flask-SocketIO.
"""

import json
import logging
import math
import os
import queue
import random
import statistics
import sys
import threading
import time
from collections import OrderedDict, deque
from dataclasses import dataclass, fields, replace
from datetime import datetime
from pathlib import Path
from typing import List, Optional

from flask import Flask, Response, jsonify, request, send_file, send_from_directory
from flask_cors import CORS
from flask_socketio import SocketIO

from .ballistics import resolve_launch, simulate
from .clubs import ClubType
from .clubs.physics import (
    SHOT_SIMULATION_DEFAULTS,
    get_club_physics,
    get_club_simulation_profile,
)
from .launch_monitor import SPIN_CONFIDENCE_HIGH, SPIN_CONFIDENCE_RELIABLE, Shot, summarize_shots
from .ops243 import (
    UART_BAUD_COMMANDS,
    Direction,
    OPS243Radar,
    SpeedReading,
    set_show_raw_readings,
)
from .power import SUPPORTED_BATTERY_PROVIDERS, PowerMonitor, PowerStatus
from .profiles import ProfileStore
from .rolling_buffer.monitor import estimate_carry_with_spin, get_optimal_spin_for_ball_speed
from .session_logger import get_session_logger, init_session_logger, log_session_error
from .sim import (
    IncompleteShotError,
    PlayerState as SimPlayerState,
    PlayerUpdate,
    ShotAck,
    SimError,
    build_connectors,
    initial_shot_counter,
    load_sim_config,
    resolve_shot,
)
from .speed_correction import correct_ball_speed
from .spin_estimate import calculated_spin_rpm
from .startup_status import StartupStatusReporter, configured_startup_components
from .swing_speed import SwingSpeedEvent

# Configure logging
logger = logging.getLogger(__name__)

REPO_ROOT = Path(__file__).resolve().parents[2]
FRONTEND_DIST_DIR = REPO_ROOT / "ui" / "dist"
FRONTEND_SOURCE_DIR = REPO_ROOT / "ui"


app = Flask(__name__, static_folder=str(FRONTEND_DIST_DIR), static_url_path="")
CORS(app)
socketio = SocketIO(app, cors_allowed_origins="*", async_mode="threading")

# Global state
monitor = None
power_monitor: Optional[PowerMonitor] = None
battery_provider: str | None = None
mock_mode: bool = False
debug_mode: bool = False
mock_swing_speed_mode: bool = False
debug_log_file = None
debug_log_path: Optional[Path] = None
# Created lazily so importing the server (in tests, in tooling) never writes
# to the real config directory.
profile_store: Optional[ProfileStore] = None


def get_profile_store() -> ProfileStore:
    """The profile roster. Single source of truth for the active selection."""
    global profile_store  # pylint: disable=global-statement
    if profile_store is None:
        profile_store = ProfileStore()
    return profile_store


TRAINING_IMPLEMENT_LABELS = {
    "driver": "Driver",
    "superspeed-light": "SuperSpeed Light",
    "superspeed-medium": "SuperSpeed Medium",
    "superspeed-heavy": "SuperSpeed Heavy",
    "speed-stick-light": "SuperSpeed Light",
    "speed-stick-medium": "SuperSpeed Medium",
    "speed-stick-heavy": "SuperSpeed Heavy",
    "stack": "Stack",
    "stack-0g": "Stack 0g",
    "stack-60g": "Stack 60g",
    "stack-100g": "Stack 100g",
    "stack-120g": "Stack 120g",
    "stack-160g": "Stack 160g",
    "stack-180g": "Stack 180g",
    "stack-200g": "Stack 200g",
    "stack-220g": "Stack 220g",
    "stack-240g": "Stack 240g",
    "stack-260g": "Stack 260g",
    "stack-280g": "Stack 280g",
    "stack-300g": "Stack 300g",
    "rypstick": "Rypstick",
    "rypstick-0w": "Rypstick 0 Weights",
    "rypstick-1w": "Rypstick 1 Weight",
    "rypstick-2w": "Rypstick 2 Weights",
    "rypstick-3w": "Rypstick 3 Weights",
    "rypstick-3w-cw": "Rypstick 3 Weights + Counterweight",
    "custom": "Custom",
}

# K-LD7 angle radars (vertical = launch angle, horizontal = club path)
kld7_vertical = None
kld7_horizontal = None

# TI IWR6843 L3 rolling-buffer capture + LCMF-v1 launch angle.
iwr6843_runtime = None
iwr6843_runtime_config: dict = {"enabled": False}
camera_capture_runtime = None
camera_capture_config: dict = {"enabled": False}
camera_replay_manager = None
camera_reference_ball_tracker = None
camera_ball_flight_reference_tracker = None

# Optional LIS3DH enclosure orientation used to compensate TI mount tilt.
inclinometer_service = None
inclinometer_runtime_config: dict = {"enabled": False}

# Ballistic model toggle. Shot carry comes from the physics simulator whenever
# a vertical launch angle is available. Operators can explicitly disable it;
# missing launch inputs always fall back to the legacy table estimator.
ballistics_enabled: bool = True

# Simulator connectors (optional). Populated in main() from config/sim.json +
# CLI flags; shots fan out to every connected connector. Player/club state is
# shared across all of them.
sim_connectors: List = []
# Seed the shot counter from the clock so ShotNumber strictly increases across
# server restarts. Some sims (e.g. OpenGolfSim's Developer API) reject any
# ShotNumber <= the highest they've seen, and that counter persists across
# reconnects — a per-run reset to 1 would get every shot dropped. Uses epoch
# *seconds* (see initial_shot_counter): epoch millis overflow GSPro's 32-bit
# ShotNumber field and every shot comes back 501 "Bad format".
sim_player_state = SimPlayerState(shot_counter=initial_shot_counter())

shutdown_lock = threading.Lock()
shutdown_cleanup_started = False
# One active hardware job plus two waiting shots is enough for normal golf
# cadence without allowing a stuck peripheral to consume memory indefinitely.
_SHOT_ENRICHMENT_QUEUE_CAPACITY = 2
_SHOT_ENRICHMENT_DEADLINE_S = 20.0
# Active hardware work, the two queued jobs, and one overflow result. If more
# shots arrive, fail the oldest optional enrichment closed so OPS finalization
# can keep advancing without retaining an unbounded number of full Shot objects.
_SHOT_FINALIZATION_CAPACITY = _SHOT_ENRICHMENT_QUEUE_CAPACITY + 2
shot_enrichment_queue: queue.Queue[tuple[Shot, str, float | None]] = queue.Queue(
    maxsize=_SHOT_ENRICHMENT_QUEUE_CAPACITY
)
shot_enrichment_task = None
shot_enrichment_task_lock = threading.Lock()
_shot_sequence_number = 0
_shot_sequence_lock = threading.Lock()
_shot_callback_lock = threading.Lock()
_shot_finalization_lock = threading.Lock()
_shot_finalization_condition = threading.Condition(_shot_finalization_lock)
_shot_finalization_order: deque[int] = deque()
_shot_finalization_registered: dict[int, "_RegisteredShotFinalization"] = {}
_shot_finalization_ready: dict[int, "_PendingShotFinalization"] = {}
_shot_finalization_running = False
_shot_finalization_worker: threading.Thread | None = None
# Shots whose OPS metrics were shown by on_shot_preview() and are waiting for
# their synced on_shot_detected() call, keyed by Shot.timestamp (the UI's row
# identity). Guarded by _shot_callback_lock. Bounded so a preview whose final
# callback never arrives cannot leak.
_PREVIEWED_SHOTS_CAPACITY = 16
_previewed_shots: "OrderedDict[datetime, _ShotPreview]" = OrderedDict()


@dataclass(frozen=True)
class _ShotEnrichmentResult:
    """Optional hardware outputs needed by required shot finalization."""

    iwr6843_ms: float | None = None
    kld7_ms: float | None = None
    camera_capture_ms: float | None = None


@dataclass(frozen=True)
class _ShotPreview:
    """Outcome of the early OPS-only emit for one shot."""

    emitted: bool
    initial_ui_ms: float | None


@dataclass(frozen=True)
class _PendingShotFinalization:
    """A completed enrichment waiting for its detection-order publication turn."""

    shot: Shot
    emit_event: str
    initial_ui_ms: float | None
    enrichment: _ShotEnrichmentResult


@dataclass(frozen=True)
class _RegisteredShotFinalization:
    """OPS-only fallback retained until optional enrichment reaches its deadline."""

    shot: Shot
    emit_event: str
    initial_ui_ms: float | None
    deadline_monotonic: float | None


def _assign_shot_number(shot: Shot) -> None:
    """Give a shot one stable session identity before any async work starts."""
    global _shot_sequence_number  # pylint: disable=global-statement

    with _shot_sequence_lock:
        if shot.shot_number is None:
            _shot_sequence_number += 1
            shot.shot_number = _shot_sequence_number
        else:
            _shot_sequence_number = max(_shot_sequence_number, shot.shot_number)


def _reset_shot_sequence() -> None:
    """Start shot identities at one for a newly started logging session."""
    global _shot_sequence_number  # pylint: disable=global-statement
    global _shot_finalization_running  # pylint: disable=global-statement

    with _shot_sequence_lock:
        _shot_sequence_number = 0
    with _shot_finalization_condition:
        _shot_finalization_order.clear()
        _shot_finalization_registered.clear()
        _shot_finalization_ready.clear()
        _shot_finalization_running = False
        _shot_finalization_condition.notify_all()


def _register_shot_for_finalization(
    shot: Shot,
    *,
    emit_event: str = "shot_update",
    initial_ui_ms: float | None = None,
    needs_watchdog: bool = False,
) -> None:
    """Record callback order and the bounded OPS-only fallback for a shot."""
    if shot.shot_number is None:
        raise ValueError("shot must have a stable number before registration")
    with _shot_finalization_condition:
        if shot.shot_number in _shot_finalization_registered:
            raise ValueError(f"shot #{shot.shot_number} is already registered")
        _shot_finalization_order.append(shot.shot_number)
        _shot_finalization_registered[shot.shot_number] = _RegisteredShotFinalization(
            shot=shot,
            emit_event=emit_event,
            initial_ui_ms=initial_ui_ms,
            deadline_monotonic=(
                time.monotonic() + _SHOT_ENRICHMENT_DEADLINE_S if needs_watchdog else None
            ),
        )
        _ensure_shot_finalization_worker_locked()
        _shot_finalization_condition.notify_all()


def _ensure_shot_finalization_worker_locked() -> None:
    """Start the exclusive finalization worker; caller holds the condition lock."""
    global _shot_finalization_worker  # pylint: disable=global-statement

    if _shot_finalization_worker is not None and _shot_finalization_worker.is_alive():
        return
    _shot_finalization_worker = threading.Thread(
        target=_shot_finalization_worker_loop,
        name="shot-finalization",
        daemon=True,
    )
    _shot_finalization_worker.start()


def _shot_finalization_worker_loop() -> None:
    """Exclusively finalize ready, overdue, or capacity-evicted shots in order."""
    global _shot_finalization_running  # pylint: disable=global-statement
    global _shot_finalization_worker  # pylint: disable=global-statement

    current_thread = threading.current_thread()
    try:
        while True:
            with _shot_finalization_condition:
                while True:
                    if not _shot_finalization_order:
                        _shot_finalization_running = False
                        if _shot_finalization_worker is current_thread:
                            _shot_finalization_worker = None
                        _shot_finalization_condition.notify_all()
                        return

                    next_shot_number = _shot_finalization_order[0]
                    registered = _shot_finalization_registered[next_shot_number]
                    pending = _shot_finalization_ready.get(next_shot_number)
                    deadline_expired = (
                        registered.deadline_monotonic is not None
                        and time.monotonic() >= registered.deadline_monotonic
                    )
                    over_capacity = len(_shot_finalization_order) > _SHOT_FINALIZATION_CAPACITY
                    if pending is not None or deadline_expired or over_capacity:
                        _shot_finalization_order.popleft()
                        del _shot_finalization_registered[next_shot_number]
                        _shot_finalization_ready.pop(next_shot_number, None)
                        _shot_finalization_running = True
                        _shot_finalization_condition.notify_all()
                        break

                    _shot_finalization_running = False
                    wait_timeout_s = None
                    if registered.deadline_monotonic is not None:
                        wait_timeout_s = max(
                            0.0,
                            registered.deadline_monotonic - time.monotonic(),
                        )
                    _shot_finalization_condition.wait(timeout=wait_timeout_s)

            if pending is None:
                reason = "deadline" if deadline_expired else "coordinator capacity"
                logger.warning(
                    "[SERVER] Shot #%d optional enrichment exceeded %s; finalizing OPS-only",
                    next_shot_number,
                    reason,
                )
                pending = _PendingShotFinalization(
                    shot=registered.shot,
                    emit_event=registered.emit_event,
                    initial_ui_ms=registered.initial_ui_ms,
                    enrichment=_ShotEnrichmentResult(),
                )
            elif pending.shot is not registered.shot:
                for shot_field in fields(Shot):
                    setattr(
                        registered.shot,
                        shot_field.name,
                        getattr(pending.shot, shot_field.name),
                    )
                pending = replace(pending, shot=registered.shot)

            try:
                _finalize_shot_detected(
                    pending.shot,
                    emit_event=pending.emit_event,
                    initial_ui_ms=pending.initial_ui_ms,
                    enrichment=pending.enrichment,
                )
            except Exception as error:  # pylint: disable=broad-exception-caught
                logger.error(
                    "[SERVER] Ordered shot finalization failed: %s",
                    error,
                    exc_info=True,
                )
                log_session_error(
                    "Ordered shot finalization failed",
                    component="server",
                    context={
                        "stage": "ordered_finalization",
                        "shot_number": pending.shot.shot_number,
                        "ball_speed_mph": pending.shot.ball_speed_mph,
                    },
                    exc=error,
                )
            finally:
                with _shot_finalization_condition:
                    _shot_finalization_running = False
                    _shot_finalization_condition.notify_all()
    finally:
        with _shot_finalization_condition:
            _shot_finalization_running = False
            if _shot_finalization_worker is current_thread:
                _shot_finalization_worker = None
            _shot_finalization_condition.notify_all()


def _shot_number_for_log(shot: Shot, session_log) -> int:
    """Use detection identity, retaining compatibility for direct helper calls."""
    if shot.shot_number is not None:
        return shot.shot_number
    return session_log.stats.get("shots_detected", 0) + 1


def _run_shutdown_step(name: str, callback) -> None:
    """Run one shutdown step without preventing later hardware cleanup."""
    started = time.monotonic()
    try:
        callback()
    except Exception:
        logger.warning("[SERVER] Shutdown cleanup failed during %s", name, exc_info=True)
    finally:
        elapsed_ms = (time.monotonic() - started) * 1000
        logger.info("[SERVER] Shutdown step %s completed in %.1fms", name, elapsed_ms)


def _cleanup_hardware_for_shutdown() -> bool:
    """Stop hardware resources and report whether this caller owned cleanup."""
    global shutdown_cleanup_started  # pylint: disable=global-statement

    with shutdown_lock:
        if shutdown_cleanup_started:
            logger.info("[SERVER] Shutdown cleanup already started")
            return False
        shutdown_cleanup_started = True

    if kld7_vertical:
        _run_shutdown_step("K-LD7 vertical stop", kld7_vertical.stop)
    if kld7_horizontal:
        _run_shutdown_step("K-LD7 horizontal stop", kld7_horizontal.stop)
    if inclinometer_service:
        _run_shutdown_step("inclinometer stop", inclinometer_service.stop)
    if iwr6843_runtime:
        _run_shutdown_step("IWR6843 stop", iwr6843_runtime.stop)
    if power_monitor:
        _run_shutdown_step("battery monitor stop", power_monitor.stop)
    if camera_capture_runtime:
        _run_shutdown_step("camera capture stop", camera_capture_runtime.stop)

    _run_shutdown_step("launch monitor stop", stop_monitor)

    for connector in sim_connectors:
        _run_shutdown_step(f"simulator connector stop ({connector.name})", connector.stop)

    return True


def _shutdown_process_after_delay(delay_s: float = 0.5) -> None:
    """Give the HTTP/WebSocket response time to flush, then clean up and exit."""
    time.sleep(delay_s)
    if not _cleanup_hardware_for_shutdown():
        return
    logger.info("[SERVER] Goodbye")
    os._exit(0)


# Max smash factor adjustment in degrees (clamped to prevent floor-dependence)
_MAX_SMASH_ADJ_LOW = -3.0  # max degrees to subtract for thin/toe hits
_MAX_SMASH_ADJ_HIGH = 2.0  # max degrees to add for high-face hits

# Degrees of launch angle change per 0.01 smash factor unit
_SMASH_DEG_PER_HUNDREDTH_LOW = 0.4  # below optimal (thin hits penalized more)
_SMASH_DEG_PER_HUNDREDTH_HIGH = 0.2  # above optimal

# Spin rate adjustment: degrees per 500 rpm deviation from optimal
_SPIN_DEG_PER_500RPM = 0.3
# Max spin adjustment in degrees (clamped like smash)
_MAX_SPIN_ADJ = 2.0

# Radar launch sanity guard. These windows are intentionally wide:
# they are meant to catch obvious K-LD7 false positives, not to micromanage
# normal shot-to-shot variation or mishits.
_RADAR_SANITY_LOW_CONF_BONUS_DEG = 5.0


def _react_app_dir() -> Path:
    """Return the best available directory containing the React index file."""
    candidates = [
        Path(app.static_folder) if app.static_folder else FRONTEND_DIST_DIR,
        FRONTEND_DIST_DIR,
        FRONTEND_SOURCE_DIR,
    ]
    for candidate in candidates:
        if (candidate / "index.html").is_file():
            return candidate
    return candidates[0]


def estimate_launch_angle(
    club: ClubType,
    ball_speed_mph: float,
    club_speed_mph: Optional[float] = None,
    spin_rpm: Optional[float] = None,
) -> tuple:
    """
    Estimate launch angle from club type, ball speed, and optional smash/spin data.

    Uses TrackMan averages as baseline, then adjusts for:
    - Ball speed deviation from club average
    - Smash factor deviation from optimal (if club_speed provided)
    - Spin rate deviation from optimal (if spin_rpm provided)

    Returns (vertical_angle, confidence).
    """
    physics = get_club_physics(club)

    # Slower than average → higher launch, faster → lower launch
    speed_delta = ball_speed_mph - physics.average_ball_speed_mph
    adjustment = -speed_delta * physics.launch_deg_per_mph

    confidence = 0.2

    # Smash factor adjustment: compare actual smash to optimal for this club
    if club_speed_mph is not None and club_speed_mph > 0:
        smash_factor = ball_speed_mph / club_speed_mph
        smash_delta = smash_factor - physics.optimal_smash

        if smash_delta < 0:
            smash_adj = max(_MAX_SMASH_ADJ_LOW, smash_delta * 100 * _SMASH_DEG_PER_HUNDREDTH_LOW)
        else:
            smash_adj = min(_MAX_SMASH_ADJ_HIGH, smash_delta * 100 * _SMASH_DEG_PER_HUNDREDTH_HIGH)
        adjustment += smash_adj

        confidence = 0.35

    # Spin rate adjustment: compare actual spin to optimal for this club/speed
    if spin_rpm is not None and spin_rpm > 0:
        optimal_spin = get_optimal_spin_for_ball_speed(ball_speed_mph, club)
        spin_delta = spin_rpm - optimal_spin
        spin_adj = (spin_delta / 500.0) * _SPIN_DEG_PER_500RPM
        spin_adj = max(-_MAX_SPIN_ADJ, min(_MAX_SPIN_ADJ, spin_adj))
        adjustment += spin_adj

        if confidence >= 0.35:
            confidence = 0.5
        else:
            confidence = 0.35

    launch_angle = max(5.0, round(physics.optimal_launch_deg + adjustment, 1))

    return (launch_angle, confidence)


def _radar_launch_base_delta_deg(club: ClubType) -> float:
    """Return a conservative club-family window for radar launch sanity checks."""
    if club in {ClubType.PW, ClubType.GW, ClubType.SW, ClubType.LW}:
        return 22.0
    if club in {ClubType.IRON_6, ClubType.IRON_7, ClubType.IRON_8, ClubType.IRON_9}:
        return 20.0
    return 18.0
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

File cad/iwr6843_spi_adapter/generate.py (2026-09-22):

"""Generate the IWR6843LEVM -> Raspberry Pi 5 SPI adapter KiCad project.

Run with KiCad's bundled Python (it needs the ``pcbnew`` module):

    /Applications/KiCad/KiCad.app/Contents/Frameworks/Python.framework/Versions/Current/bin/python3 \
        cad/iwr6843_spi_adapter/generate.py

Single source of truth: ``PARTS`` and ``NETS`` below drive BOTH the schematic
and the PCB, so the two cannot drift apart. ``make check`` style validation is
done afterwards with kicad-cli (ERC, DRC + schematic parity), see README.md.

Every pinout / land pattern here is taken from the manufacturer documents,
not from memory or from generic KiCad library parts:

* IWR6843LEVM J1 pin map: TI PROC116A schematic sheets 5, 8, 13 (SPI-A via the
  TS3A5018 mux, 0-ohm R7/R9/R10/R11/R12, VIOIN = RADAR_3V3) and BOM
  (J1 = Samtec QSH-030-01-L-D-A).
* QTH-030-01-L-D-A land pattern: Samtec "Recommended PCB layout for
  QTH-XXX-XX-X-D-XXX", Rev D.  Mated height with QSH-01: 5.00 mm (QTH print
  Table 1).
* SN74LVC2G34 pinout (1A=1, 1Y=6, 2A=3, 2Y=4, GND=2, VCC=5), Ioff
  partial-power-down, DBV0006A land pattern: TI datasheet SCES370.
"""

from __future__ import annotations

import json
import re
import uuid
from dataclasses import dataclass, field
from pathlib import Path

HERE = Path(__file__).resolve().parent
PROJECT = "iwr6843_spi_adapter"
FP_LIB = "openflight_adapter"
KICAD = Path("/Applications/KiCad/KiCad.app/Contents/SharedSupport")
SYM_DIR = KICAD / "symbols"
FP_DIR = KICAD / "footprints"

# Deterministic UUIDs so regenerating produces a stable diff.
_NS = uuid.UUID("6f8d2f3e-2a8e-4c1b-9d0a-0b5e1d7c9a11")


def uid(name: str) -> str:
    return str(uuid.uuid5(_NS, name))


ROOT_UUID = uid("root-sheet")

# ---------------------------------------------------------------------------
# Design data (single source of truth)
# ---------------------------------------------------------------------------


@dataclass
class Part:
    ref: str
    lib_id: str
    value: str
    footprint: str
    units: int = 1
    datasheet: str = ""
    mpn: str = ""
    manufacturer: str = ""
    description: str = ""
    # Whether the assembler places it (J2 is hand-soldered so its tails can
    # be trimmed flush; see README).
    assemble: bool = True
    # Schematic placement for each unit: list of (x, y) in mm.
    sch_at: list = field(default_factory=list)


QTH_FP = f"{FP_LIB}:Samtec_QTH-030-01-L-D-A"
DBV_FP = f"{FP_LIB}:TI_DBV0006A"
R0603 = "Resistor_SMD:R_0603_1608Metric"
C0603 = "Capacitor_SMD:C_0603_1608Metric"
HDR_FP = "Connector_PinHeader_2.54mm:PinHeader_1x11_P2.54mm_Vertical"
LVC_DS = "https://www.ti.com/lit/ds/symlink/sn74lvc2g34.pdf"

PARTS = [
    Part(
        "J1",
        "Connector_Generic_MountingPin:Conn_02x30_Odd_Even_MountingPin",
        "QTH-030-01-L-D-A",
        QTH_FP,
        mpn="QTH-030-01-L-D-A",
        manufacturer="Samtec",
        description="0.5mm 2x30 Q Strip terminal, alignment pins, mates QSH-030-01",
        datasheet="https://suddendocs.samtec.com/prints/qth-xxx-xx-x-d-xx-mkt.pdf",
        sch_at=[(55.88, 101.6)],
    ),
    Part(
        "J2",
        "Connector_Generic:Conn_01x11",
        "Pi5_jumpers",
        HDR_FP,
        mpn="",
        description="1x11 2.54mm male pin header (customer installs, trim tails flush)",
        assemble=False,
        sch_at=[(254.0, 76.2)],
    ),
    # U1: radar-powered, Pi -> radar (ch2 = MOSI, ch1 = SCLK)
    Part(
        "U1",
        "74xGxx:74LVC2G34",
        "SN74LVC2G34DBVR",
        DBV_FP,
        units=3,
        mpn="SN74LVC2G34DBVR",
        manufacturer="Texas Instruments",
        description="Dual buffer, Ioff partial-power-down, SOT-23-6",
        datasheet=LVC_DS,
        sch_at=[(160.02, 45.72), (160.02, 60.96), (160.02, 30.48)],
    ),
    # U2: radar-powered, Pi -> radar (ch2 = CS, ch1 = spare, input grounded)
    Part(
        "U2",
        "74xGxx:74LVC2G34",
        "SN74LVC2G34DBVR",
        DBV_FP,
        units=3,
        mpn="SN74LVC2G34DBVR",
        manufacturer="Texas Instruments",
        description="Dual buffer, Ioff partial-power-down, SOT-23-6",
        datasheet=LVC_DS,
        sch_at=[(160.02, 101.6), (160.02, 86.36), (187.96, 30.48)],
    ),
    # U3: Pi-powered, radar -> Pi (ch1 = HOST_INTR, ch2 = MISO)
    Part(
        "U3",
        "74xGxx:74LVC2G34",
        "SN74LVC2G34DBVR",
        DBV_FP,
        units=3,
        mpn="SN74LVC2G34DBVR",
        manufacturer="Texas Instruments",
        description="Dual buffer, Ioff partial-power-down, SOT-23-6",
        datasheet=LVC_DS,
        sch_at=[(160.02, 132.08), (160.02, 147.32), (215.9, 30.48)],
    ),
    Part(
        "C1",
        "Device:C",
        "100nF",
        C0603,
        mpn="CL10B104KB8NNNC",
        manufacturer="Samsung Electro-Mechanics",
        description="100nF 50V X7R 0603 MLCC",
        sch_at=[(132.08, 172.72)],
    ),
    Part(
        "C2",
        "Device:C",
        "100nF",
        C0603,
        mpn="CL10B104KB8NNNC",
        manufacturer="Samsung Electro-Mechanics",
        description="100nF 50V X7R 0603 MLCC",
        sch_at=[(142.24, 172.72)],
    ),
    Part(
        "C3",
        "Device:C",
        "100nF",
        C0603,
        mpn="CL10B104KB8NNNC",
        manufacturer="Samsung Electro-Mechanics",
        description="100nF 50V X7R 0603 MLCC",
        sch_at=[(152.4, 172.72)],
    ),
    Part(
        "R1",
        "Device:R",
        "100k",
        R0603,
        mpn="RC0603FR-07100KL",
        manufacturer="YAGEO",
        description="100k 1% 0603 resistor",
        sch_at=[(203.2, 101.6)],
    ),
    Part(
        "R2",
        "Device:R",
        "100k",
        R0603,
        mpn="RC0603FR-07100KL",
        manufacturer="YAGEO",
        description="100k 1% 0603 resistor",
        sch_at=[(203.2, 60.96)],
    ),
    Part(
        "R3",
        "Device:R",
        "100k",
        R0603,
        mpn="RC0603FR-07100KL",
        manufacturer="YAGEO",
        description="100k 1% 0603 resistor",
        sch_at=[(203.2, 45.72)],
    ),
    Part(
        "R4",
        "Device:R",
        "100k",
        R0603,
        mpn="RC0603FR-07100KL",
        manufacturer="YAGEO",
        description="100k 1% 0603 resistor",
        sch_at=[(119.38, 147.32)],
    ),
    Part(
        "R5",
        "Device:R",
        "100k",
        R0603,
        mpn="RC0603FR-07100KL",
        manufacturer="YAGEO",
        description="100k 1% 0603 resistor",
        sch_at=[(119.38, 132.08)],
    ),
    Part(
        "R6",
        "Device:R",
        "33",
        R0603,
        mpn="RC0603FR-0733RL",
        manufacturer="YAGEO",
        description="33R 1% 0603 resistor",
        sch_at=[(203.2, 132.08)],
    ),
    Part(
        "R7",
        "Device:R",
        "33",
        R0603,
        mpn="RC0603FR-0733RL",
        manufacturer="YAGEO",
        description="33R 1% 0603 resistor",
        sch_at=[(203.2, 147.32)],
    ),
]
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

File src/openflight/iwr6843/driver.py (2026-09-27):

"""IWR6843 serial driver — the host side of the L3-dump firmware contract.

Firmware v3+ speaks a SINGLE UART (the CP2105 Enhanced interface) at
1,041,667 baud for both CLI commands and the binary dump; the dump is framed
by its "ILD1" magic plus the header-declared length, so CLI echo and payload
can share the pipe. Hardware-validated 2026-07-13 at 100% of wire rate.

Gotchas baked in (each cost a debugging session):
- DTR/RTS must be held low on open (TI EVMs tie them to reset/boot mode).
- One serial handle only — two handles on one tty steal each other's bytes.
- The CP2105 can stall a stream for seconds (cp210x -110 control timeouts)
  and resume; the reader waits out gaps up to ``stall_tolerance_s``.
"""

from __future__ import annotations

import glob
import logging
import re
import time
from collections import deque
from collections.abc import Callable
from dataclasses import dataclass

import serial

from openflight.iwr6843.autotrigger import AutoTriggerConfig
from openflight.iwr6843.dump import HEADER, MAGIC, parse_header, payload_nbytes
from openflight.iwr6843.reduced import StripRequest, encode_strip_request, overview_nbytes

BAUD = 1_041_667
_PORT_GLOBS = ("/dev/ttyUSB*", "/dev/tty.SLAB_USBtoUART*")

# The firmware's unsolicited shot notice (l3_dump.c l3_autoWriteNotice).
AUTO_TRIGGER_NOTICE_MAGIC = "ILTRG1"
_NOTICE_RE = re.compile(
    rb"ILTRG1 seq=(\d+) age_ms=(\d+) delay=(\d+) end=(\d+) slope_q=(\d+) frames=(\d+)\r?\n?"
)
_NOTICE_TAIL_BYTES = 96  # longer than any notice: keep a split line's start


@dataclass(frozen=True)
class AutoTriggerNotice:
    """The radar detected a shot and is holding its frozen ring."""

    seq: int
    age_ms: int  # freeze request -> notice written
    delay_frames: int  # detection -> freeze request
    end_bin: int
    slope_q: int
    n_frames: int
    received_at: float

    def detection_timestamp(self, frame_period_s: float) -> float:
        """Host time of the detection (the club reaching the tee, ~impact)."""
        return self.received_at - self.age_ms / 1000.0 - self.delay_frames * frame_period_s


def parse_auto_trigger_notice(line: bytes, *, received_at: float) -> AutoTriggerNotice | None:
    """One notice line, or None if it is not one."""
    match = _NOTICE_RE.search(line)
    if match is None:
        return None
    seq, age_ms, delay, end, slope_q, frames = (int(group) for group in match.groups())
    return AutoTriggerNotice(seq, age_ms, delay, end, slope_q, frames, received_at)


logger = logging.getLogger(__name__)


def _dump_nbytes(buf: bytearray) -> int:
    """Total size of a dump (or strip response) from its header and tables."""
    metadata = parse_header(buf)
    return metadata["header_nbytes"] + payload_nbytes(metadata, buf)


def open_port(port: str, baud: int = BAUD, timeout: float = 0.3) -> serial.Serial:
    """DTR/RTS-safe serial open."""
    ser = serial.Serial()
    ser.port, ser.baudrate, ser.timeout = port, baud, timeout
    ser.dtr = False
    ser.rts = False
    ser.open()
    return ser
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

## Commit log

2026-09-22 fix(rolling-buffer): never leave the OPS243 un-armed; show shots before clock sync
    Blue dump light stuck on / no more hits:
    - SoundTrigger re-arms on every idle timeout (watchdog), so a failed
    re-arm or a dump without a recognisable start marker can no longer
    leave the radar idle forever.
    - Any exception after a dump is read still re-arms (try/finally),
    keeping clock sync strictly before re-arm (net-impact deadlock fix).
    Shot latency (sound trigger):
    - Accepted captures are returned un-synced/un-armed. The monitor
    processes the capture, calls the new shot_preview_callback (server
    emits the OPS "shot" event immediately), then finish_capture() does
    the ~36-read clock sync and re-a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
    [monitor.py, server.py, session_logger.py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]
2026-09-22 feat(cad): IWR6843LEVM J1 -> Raspberry Pi 5 SPI adapter (rev A)
    2-layer 34 x 25.9 mm board: Samtec QTH-030-01-L-D-A mates the LEVM's
    J1 (bottom-to-bottom, 5.00 mm), three SN74LVC2G34 Ioff buffers protect
    whichever side is unpowered, and a 1x11 jumper header goes to the Pi 5
    SPI0 pins. Generated from generate.py / build_pcb.py (single netlist);
    ERC, DRC with schematic parity, and Gerber checks are clean. Includes
    fab outputs and README with LEVM S1.4 setup, wiring and bring-up checks.
    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
    [bom.csv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]
2026-09-22 feat(cad): PCBWay turnkey BOM/CPL, assembly drawings, export_fab.sh
    Real MPNs and manufacturers for all assembled parts (single source in
    generate.py), PCBWay-format BOM, CPL without the hand-soldered J2
    header, scaled assembly drawings with pad numbers, and export_fab.sh
    that regenerates and refuses to export on any ERC/DRC error.
    [bom.csv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]
2026-09-22 chore(cad): bundle PCBWay assembly files into one zip
    [iwr6843_spi_adapter-B_Cu.gbl, iwr6843_spi_adapter-B_Mask.gbs, iwr6843_spi_adapter-B_Paste.gbp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]
2026-09-23 fix(iwr6843): withhold launch angles the R10 comparison showed are unreliable
    A 42-shot session paired with a Garmin R10 (via GSPro) showed the LCMF
    estimator "accepting" launch angles off by 6-38 deg, which the carry
    model turned into +/-20 yd swings and exact 0 yd carries (launch <= 0
    lands the simulated ball immediately). Three accepted-result shapes
    were wrong almost every time and are now withheld from the displayed
    and carry launch angle; the shot falls back to the labelled estimate:
    - single-channel results (other channel at its grid edge or disagreeing
    by >8 deg): 11 of 12 off by 6-34 deg
    - accepted_track_speed_warning (TI track disagrees with OPS ball speed,
    no OPS-compatible t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
    [server.py]
2026-09-23 fix(ops243): recover a stuck blue light in ~1 s instead of the 30 s watchdog
    Two known ways to leave the OPS243 idle after a dump (blue light on, no
    hits read) were only recovered by the 30 s idle watchdog:
    - Orphaned dumps. wait_for_hardware_trigger clears the input buffer on
    entry; a dump started between the re-arm and the next wait (e.g. the
    ball hitting the net) lost its sample_time/trigger_time header, and
    the remaining I/Q body was discarded as idle noise. The wait now
    treats >=512 non-capture bytes followed by 0.3 s of quiet as an
    orphaned dump, returns early, and the trigger re-arms immediately
    (logged as an orphan_dump trigger event). Small idle noise (clock
    replies,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
    [ops243.py, test_ops243_orphan_dump.py, test_sound_trigger_rearm.py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]
2026-09-23 fix(iwr6843): report topped balls at a low launch instead of a clean-strike estimate
    Single-channel LCMF results are withheld and fall back to the club-table
    estimate, which assumes a clean strike (16-28 deg). Paired R10 sessions
    (2026-09-23, 69 shots) showed that when the floor-reflection channel (two8)
    of such a result reads <= 5 deg, the ball was topped every time (6 of 6,
    R10 2.0-4.3 deg), so those 20-35 yd tops were carried ~95 yd.
    Those shots now use two8, floored at 2 deg, with the trigger status
    "accepted_low_launch_two8". Carry error on the six shots drops from a median
    of ~61 yd to ~9 yd; no other paired shot changes. Two-channel results, OPS-
    incompatible tracks and channels on a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
    [lcmf.py, server.py]
2026-09-23 Revert "fix(iwr6843): report topped balls at a low launch instead of a clean-strike estimate"
    This reverts commit 5cd37cb.
    [lcmf.py, server.py]
2026-09-23 feat(launch): fall back to the player's own typical launch, withhold weak-echo IWR readings
    The club-table launch estimate assumes a tour-average strike and guessed
    22-28 deg for 9-irons this player launches at ~11 deg. Paired R10 data
    (2026-09-23, 70 shots) also showed IWR readings built from <= 8 frames --
    a ball echo near the noise floor -- were typically 3.7 deg off with
    +/-13 deg misses, against 1.2 deg for the rest.
    * New LaunchHistory: per profile and club, the last 30 IWR launches applied
    with a strong echo (> 8 frames), persisted atomically to
    ~/.config/openflight/launch_history.json (OPENFLIGHT_LAUNCH_HISTORY_PATH
    overrides; tests are isolated in conftest). The median of >=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
    [server.py]
2026-09-24 Revert launch-angle changes: launch gate and personal launch history
    Restores the upstream IWR6843 launch-angle behavior at the user's request.
    This reverts commit 09a7c77 (personal launch history, weak-echo withholding)
    and commit 379a9b2 (withhold single-channel, track-speed-warning and
    non-positive launches). The blue-light, latency and SPI-adapter work stays.
    [server.py]
2026-09-24 docs(plans): IWR6843 on-chip data reduction (overview + strips)
    Offline study on 70 R10-paired shots: a gate-trimmed uint16 power overview
    plus +/-1-bin complex strips along the Pi-selected track cut the IWR
    transfer from 537 KB (5.3 s) to ~93 KB (~0.9 s) on baseline shots and
    ~223 KB (~2.2 s) on OPS-guided ones, with launch-angle accuracy vs the R10
    unchanged. All tracking and estimation stays on the Pi.
2026-09-24 fix(iwr6843): keep stored IQ8 samples when projecting the vertical TX pair
    project_tx_pair re-derived each IQ8 frame's scale from the kept TX pair's
    peak. When the dropped TX held the peak, the scale shrank and every sample
    was rounded a second time. pack_dump now takes the stored scales
    (iq8_scales) and raises instead of clipping a sample that does not fit; the
    projection passes them through, so it is lossless.
    Required by the on-chip reduction plan (strips must reproduce the full
    capture exactly). On the 70 R10-paired shots all stay accepted; angles move
    median 0.43 deg (max 12.3 deg) with no net accuracy change vs the R10
    (solid shots: typical 2.03 -> 2.16 deg, mean 4.00 -> 3.81 deg).
    C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
    [dump.py, test_iwr6843_pipeline.py]
2026-09-24 refactor(iwr6843): let tracking use supplied power, noise, and window means
    Phase 0b of plans/iwr6843-on-chip-reduction.md. In reduced-transfer mode
    the radar sends the per-loop power maps, noise powers, and window-scope
    static means computed from its full ring, and the Pi holds only strips of
    the capture. PreparedShotDump now accepts those products (validated for
    both scopes, shape, and positive finite noise) and exposes loop_power();
    find_ball and the OPS-guided candidate search take a power map directly;
    mti_filter takes supplied window means (compute_window_means is the shared
    definition).
    No behaviour change: supplying the computed products is covered by tests,
    and replaying the 70 R10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
    [recovery.py, shot.py, test_iwr6843_supplied_products.py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]
2026-09-24 feat(iwr6843): reduced-transfer wire format and firmware reference model
    Phase 0c of plans/iwr6843-on-chip-reduction.md.
    openflight.iwr6843.reduced defines the overview (capture header and
    per-frame tables, then both vertical-pair power maps as 1/256-octave log
    int16 over the ball-gate bins, both noise powers, and the window-scope
    static means) and the strip response (an ordinary timed dump holding only
    the requested bins, IQ8 as stored).
    * build_overview / serve_strips model the firmware from a full capture;
    the firmware must reproduce their bytes.
    * pack_overview / parse_overview are the single definition of the layout,
    with strict size, magic, version, loop-count, gate, and means ch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
    [dump.py, lcmf.py, reduced.py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]
2026-09-24 feat(iwr6843): reduced-transfer measurement path and replay evaluation
    Phase 0d of plans/iwr6843-on-chip-reduction.md -- Phase 0 complete.
    IWR6843Runtime.measure_reduced takes a ReducedSource (the radar, or
    CaptureReducedSource modelling it from a full capture): it tracks on the
    overview's power maps, fetches strips along the baseline track, and lets
    the unchanged OPS-guided search fetch its candidates' strips through a new
    refine hook. measure_capture is the public full-capture path; both share
    _measure, and process_shot is unchanged in behaviour. lcmf.track_capture
    names the baseline tracking step; prepare_lcmf_capture passes supplied
    products through; tracking.max_ball_range_m replaces t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
    [lcmf.py, recovery.py, reduced.py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]
2026-09-24 feat(firmware): on-chip overview and strips for the reduced IWR transfer
    Phase 2 of plans/iwr6843-on-chip-reduction.md (pending hardware checks).
    * reduced_overview.c/.h: portable C89 core, no TI headers or libm, that
    writes the overview (both vertical-pair power maps as log16 codes over the
    ball gate, exact noise medians via radix selection on double bits,
    window-scope means) and strip responses through a byte sink. Compiled
    for the host, it is byte-identical to reduced.py on all 80 saved field
    captures and on every synthetic shape tested (IQ8/IQ16, 2/3 TX).
    * l3_dump.c: overviewCfg, l3overview (freeze + overview, hold the ring),
    l3strip <hex> (bins of the held ring), l3release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
    [driver.py, l3_dump.c, reduced.py]
2026-09-24 perf(firmware): integer overview maths for the reduced transfer (rc2)
    rc1 passed every functional check on the radar, but the overview took
    2.96 s in firmware (~2.3 s compute): ~200 cycles per sample read, 10x the
    estimate, leaving the IWR result at ~4.5 s instead of ~2.5-3 s.
    rc2 decodes each frame's vertical-pair codes once per pass into fast
    memory and works on integers: burst MTI power is exactly
    s^2 |L c - sum c|^2 / L^2 and window power |n s c - T|^2 / n^2, each
    rounded once. The selection passes no longer go through function
    pointers. reduced.build_overview uses the same maths, so C and Python
    still match byte-for-byte (all 80 saved captures; host builds need
    -ffp-contract=off). Agai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
    [l3_dump.c, reduced.py, test_iwr6843_firmware_reduced.py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]
2026-09-24 perf(firmware): no 64-bit integer helpers in the overview maths (rc3)
    On the radar, rc2 returned only the l3overview echo: it computes before its
    first byte, and the Pi's reader counted its 4 s stall timer from the echo.
    Compiling rc2's core with the TI toolchain showed per-value calls to
    __aeabi_lmul and __aeabi_l2d -- the R4F has no 64-bit multiply or
    int64-to-double instruction.
    * reduced_overview.c: every intermediate is an exact integer below 2^53,
    so it is carried in doubles -- bit-identical results, no lmul/l2d. The
    median's key is kept as two 32-bit halves so the per-value work needs no
    64-bit shift helper (those now run once per pass). Still byte-identical
    to reduced.py on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
    [driver.py, test_iwr6843_driver.py, test_iwr6843_reduced_firmware.py]
2026-09-24 feat(iwr6843): reduced transfer in the live pipeline behind --iwr6843-reduced-transfer
    Phase 3 of plans/iwr6843-on-chip-reduction.md.
    * monitor: in reduced mode a trigger edge fetches the overview and the radar
    holds its ring; read_strips / finish_capture serve the runtime under one
    serial lock. New edges wait while a ring is held; an unconsumed hold is
    released after 8 s (under the firmware's 10 s); shutdown releases a hold
    before sensorStop. Overview failures fall back to an ordinary l3dump, and
    firmware without overviewCfg falls back to full dumps at startup.
    * runtime: process_shot measures a held capture with measure_reduced; any
    failure streams the held ring whole and meas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
    [monitor.py, reduced.py, runtime.py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]
2026-09-25 fix(kiosk): wait for the desktop display before launching the browser
    After a reboot openflight.service launched Chromium 8 s after starting,
    before the desktop's display server existed. Chromium logged "Missing X
    server or $DISPLAY" and exited, so the server ran headless with no kiosk
    window until a manual restart.
    launch_kiosk_browser now waits (up to 120 s, then launches anyway with a
    warning) for the :0 X socket that both browsers use -- Xwayland's under
    Wayland -- plus a 2 s settle once it appears. Tests exercise the wait with
    a real UNIX socket: already up, appearing later, and never appearing.
    [test_start_kiosk.py]
2026-09-25 feat(camera): --camera-analysis off skips the live camera estimators
    Capture and replay keep working; ball-flight and club-delivery analysis
    (about 9 s per shot on the Pi) are skipped. The horizontal goes through
    the same IWR fallback as a shot with no camera, and the experimental
    fields report skipped_analysis_off.
    [server.py, test_server.py]
2026-09-25 perf(iwr6843): batch the LCMF grid and dedupe recovery fits (bit-identical)
    The OPS-guided recovery took ~6-7 s per hard shot on the Pi, long enough
    for the 8 s hold budget to release the radar before the shot finished.
    - LCMF channel search evaluates every grid angle in one batched
    dictionary / PRESS / per-frame-median pass instead of one angle at a
    time (element-wise maths, so each angle's value is unchanged).
    - Recovery candidate search tests all pairs anchored on a point at once,
    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
2026-09-25 fix(iwr6843): release the frozen ring as soon as the OPS rejects the sound
    A sound the OPS rejected (no outbound speed, processing failure, failed
    shot validation) left the IWR6843 ring frozen for the full 8 s hold
    budget, so a real swing in that window lost its launch angle. Seen live:
    a rejected sound 5.3 s after a shot held the radar until the budget ran
    out.
    - Rejection diagnostics now carry the sound's host-clock edge time.
    - The server passes rejections to IWR6843CaptureMonitor.discard_trigger,
    which drops the matching unclaimed capture and wakes the capture thread
    to release the ring now; a rejection that arrives while the overview is
    still in flight releases it on arrival. Cap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
    [monitor.py, server.py, test_iwr6843_monitor_reduced.py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]
2026-09-26 feat(ops243): port the internal hardware trigger (upstream PR #221)
    Brings open-flight/openflight PR #221 (head 73eacc7) onto this branch as
    one change: --trigger hardware lets the OPS243-A start its rolling-buffer
    dump from its own speed trigger (ST/SM, 6 pre-trigger segments), so no
    sound detector is needed. Requires OPS243-A firmware 1.3.2+, checked at
    startup. Conflicts resolved by keeping this branch's orphaned-dump
    handling alongside the PR's re-arm recovery.
    [monitor.py, ops243.py, server.py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]
2026-09-27 feat(iwr6843): on-radar shot detector core (club track to the tee)
    Portable C89 core (auto_trigger.c) and its Python reference
    (autotrigger.py): per frame, first-TX loop-MTI power normalised by the
    frame median; fire when a straight outward track at club speed reaches
    z_min in every one of the last n frames and ends at the tee, then request
    the freeze delay_frames later. Exact integer sums, one division per value
    and integer quarter-bin line search keep C and Python bit-identical, on
    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
2026-09-27 feat(iwr6843): the radar detects the shot itself (auto trigger, rc1)
    With the OPS243 on its internal trigger there is no sound edge, and the Pi
    learns of a shot ~110 ms after impact -- too late for the 72 ms IWR ring.
    Firmware (l3_dump.c, candidate l3_dump_auto_trigger_rc1.bin):
    - The HWA re-arm task runs auto_trigger.c on each completed pre-impact
    frame's IQ16 scratch; a detection requests the same post-frame freeze
    l3dump uses.
    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
